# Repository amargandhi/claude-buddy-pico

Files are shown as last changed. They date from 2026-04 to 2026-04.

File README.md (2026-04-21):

# Claude Buddy Pico

A fun, playful Claude Code mascot brought to life with a 3D-printed case by porting Felix Rieseberg's original Claude Desktop buddy from the M5 ESP32 hardware to a custom Raspberry Pi Pico build with a bigger 2.8" display. Claude Pico sits next to your Mac, approves tool calls for [Claude Desktop](https://claude.ai/download) over Bluetooth, and reacts to what Claude is doing with a face that feels alive. One button approves, another denies, and the built-in rechargeable battery lets you take it around the office or house to keep an eye on things while you get on with your day.

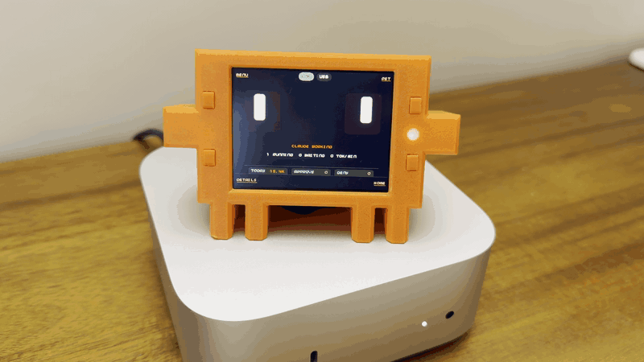
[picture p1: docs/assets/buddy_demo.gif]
Claude Buddy Pico V2 UI demo


Unofficial community port. Not produced or endorsed by Anthropic. Attribution in [NOTICE](NOTICE).

<p align="center">
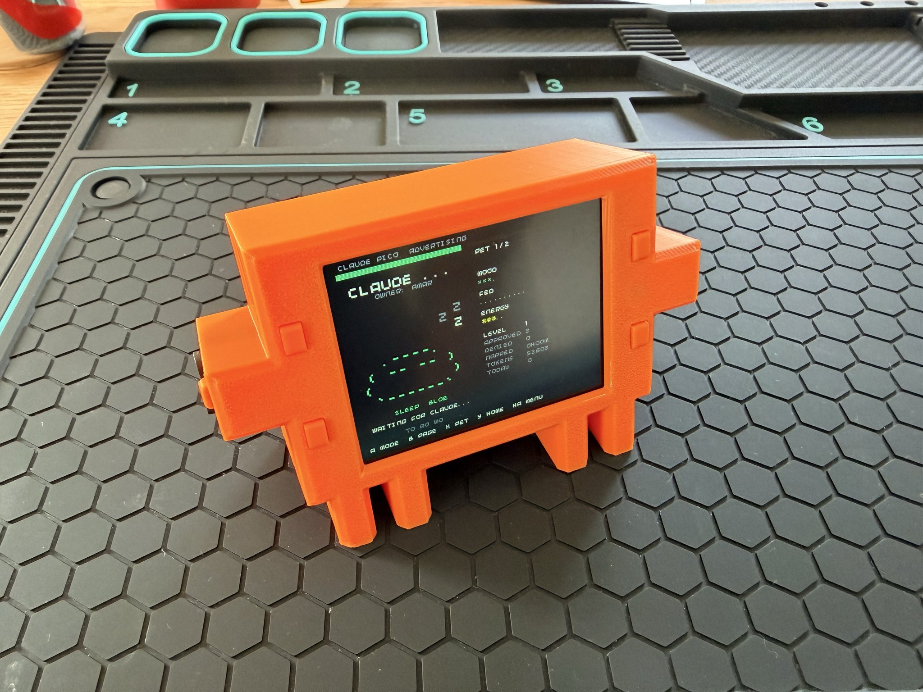
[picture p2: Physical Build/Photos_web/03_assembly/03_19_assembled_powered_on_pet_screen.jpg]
Claude Buddy Pico powered on in the printed case
  
  &nbsp;
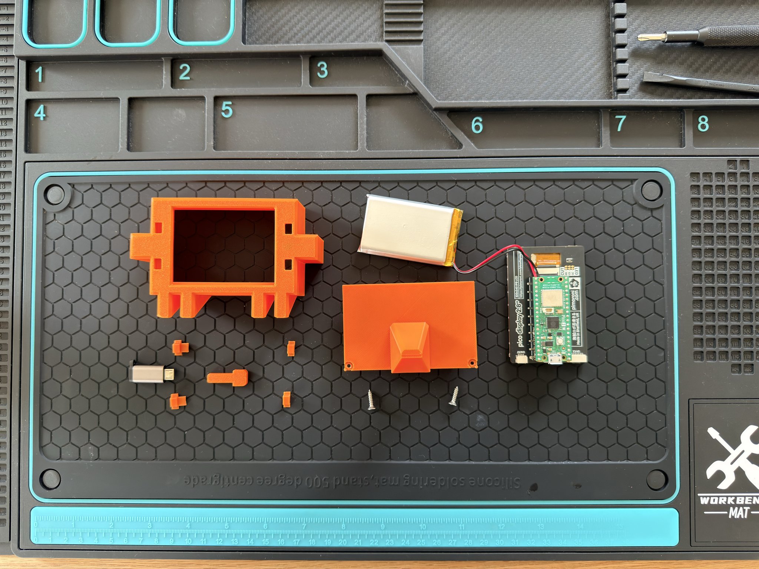
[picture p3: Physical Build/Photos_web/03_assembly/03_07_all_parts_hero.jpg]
All parts laid out: Pico 2 W, Pimoroni Display Pack 2.8, LiPo SHIM, 2000 mAh battery, 3D-printed Clawd case, M3 screws
  
</p>

Upstream: [anthropics/claude-desktop-buddy](https://github.com/anthropics/claude-desktop-buddy). Original author: [Felix Rieseberg](https://github.com/anthropics/claude-desktop-buddy/commits?author=felixrieseberg).

## What it is

- Raspberry Pi Pico 2 W + Pimoroni Display Pack 2.8 + optional LiPo SHIM and 2000 mAh battery.
- Pairs with Claude Desktop over Bluetooth Low Energy using the Hardware Buddy protocol.
- Runs tethered on USB, or untethered with the optional battery.
- 3D-printed case in the shape of Clawd. CAD in both `.step` (editable) and `.stl` (printable).
- MIT licensed; improvements and fixes are welcome.

## Pick a path

| If you want to… | Start here |
|---|---|
| Build one | [Physical Build/BUILD_GUIDE.md](Physical%20Build/BUILD_GUIDE.md) |
| Print the case | [Physical Build/CAD/](Physical%20Build/CAD) — GitHub renders `.stl` inline |
| Flash the firmware | [docs/software-setup.md](docs/software-setup.md) |
| Understand what changed from upstream | [docs/feature-matrix.md](docs/feature-matrix.md) |

## What changed from upstream

Three things matter; the rest is in [`docs/feature-matrix.md`](docs/feature-matrix.md):

- **Landscape 320×240 instead of the M5Stick portrait display.** The V2 UI is Pico-native, not a pixel copy of the original.
- **Four front buttons `A / B / X / Y` replace the M5Stick power-button semantics.** The LiPo SHIM button stays hardware-only.
- **No IMU.** Shake-to-dizzy became `Hold X`; face-down nap became `Hold Y`. Gestures are explicit.

The BLE Hardware Buddy protocol itself is unchanged — this device pairs with a stock Claude Desktop Hardware Buddy session.

## Controls

- `A`: next screen, approve prompt, advance selection
- `B`: next page, next transcript chunk, deny prompt
- `X`: next pet, raw prompt details during approvals
- `Y`: home / back
- `Hold A`: open the main menu
- `Hold X`: `dizzy` easter egg
- `Hold Y`: nap / wake
- `LiPo SHIM button`: hardware power only, never app input

Full screen-by-screen map in [`docs/user-guide.md`](docs/user-guide.md).

## Known limits

- **GIF character packs not implemented.** The transfer wire protocol works and `text` manifests render on-device; porting the upstream GIF renderer to the Pico is future work.
- **Battery percent is estimated from VSYS voltage.** No current-sense path on this build, so it's a voltage-curve approximation, not coulomb counting.
- **Case is v1.** Obvious things to improve: a proper integrated battery retainer instead of glued clips, a deeper USB cutout, tighter button-stem tolerance. The `.step` files are in the repo. Fork the case and open a PR — the v2 list is in the build guide.
- **Hardware Buddy feature gating.** If `Developer → Open Hardware Buddy…` is missing, you're on a Claude Desktop build that doesn't expose the feature yet — host-side, not firmware.

## Firmware — two paths

There are two ways to build the main firmware from the same `claude_buddy_pico` target. Both speak the same BLE protocol and pair with Claude Desktop the same way. They differ only in the on-device UI.

- **Main path — V2 with buddy animations (default).** Face expressions, animated pet, dock clock, approval screens, permissions log. Built with `BUDDY_UI_V2=1`, which is on by default.
- **Basic path — V1 monolith (fallback).** The original single-file UI from early bringup. Same BLE stack, simpler screens, no animations. Opt in with `-DBUDDY_UI_V2=OFF` at configure time. Useful if you're debugging the BLE layer and want the UI out of the way.

## Build

macOS toolchain:

```bash
scripts/bootstrap_macos.sh       # one-time
scripts/clone_deps.sh            # one-time
scripts/configure_firmware.sh    # V2 main path (default)
cmake --build build/pico
```

For the V1 basic path, configure with the flag off:

```bash
cmake -S . -B build/pico -DBUDDY_UI_V2=OFF
cmake --build build/pico
```

Either configure step produces `claude_buddy_pico.uf2` — the flag only changes which UI gets compiled in.

### Diagnostic builds

The same build also emits three smoke-test UF2s. Only flash these if something is wrong:

- `claude_buddy_pico_smoke.uf2` — hardware smoke test (display, buttons, LED)
- `claude_buddy_ble_smoke.uf2` — BLE/protocol smoke test
- `claude_buddy_pico_v2_smoke.uf2` — isolated V2 UI renderer, no BLE

If Homebrew's embedded toolchain install fails on your machine, `scripts/extract_local_toolchain.sh` extracts a workspace-local fallback. Full detail in [`docs/software-setup.md`](docs/software-setup.md).

## Flash

1. Disconnect the battery.
2. Hold `BOOTSEL`.
3. Plug USB into your Mac.
4. `cp build/pico/claude_buddy_pico.uf2 /Volumes/RP2350/`

`BOOTSEL` recovery with the battery attached is flaky on the LiPo SHIM. The battery-connected recovery path and the full story are in [`docs/hardware-build.md`](docs/hardware-build.md).

## Pair with Claude Desktop

1. Enable Developer Mode in Claude Desktop.
2. `Developer → Open Hardware Buddy…`
3. `Connect` → select `Claude Pico` → complete the passkey flow.

## Repo layout

- `src/` — active firmware targets and character renderer
- `src/ui_v2/` — V2 UI engine, screens, palette, face system, transitions
- `src/_legacy/` — archived bringup scaffold, not part of the current build
- `docs/` — protocol notes, feature matrix, limitations, and user guide
- `Physical Build/` — CAD, printable case, and the hardware build guide
- `scripts/` — bootstrap, dependency, and configure helpers
- `third_party/` — vendor SDK clones
- `toolchains/` — optional workspace-local embedded toolchain

## What to do next

- **Build the minimum version first** — Pico 2 W + Display Pack + USB cable. That proves the firmware works on your hardware before you commit to the SHIM solder.
- **Open the `.step` files** in Fusion / FreeCAD / Onshape. Fork the case and open a PR — the v2 list is in the build guide.

## Credits

The Hardware Buddy BLE protocol and the original M5Stick firmware are the work of Anthropic and are published at [anthropics/claude-desktop-buddy](https://github.com/anthropics/claude-desktop-buddy). Felix Rieseberg's original implementation is the foundation for this port. See [NOTICE](NOTICE) for attribution details.

## License

MIT. See [LICENSE](LICENSE).

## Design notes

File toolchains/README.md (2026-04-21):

# Local Toolchains

This directory is for workspace-local toolchains that do not need a system-wide install.

Use `scripts/extract_local_toolchain.sh` to unpack the cached Arm GNU embedded package here when the Homebrew cask install is not practical.

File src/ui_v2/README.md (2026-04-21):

# V2 UI module

The V2 UI engine for Claude Buddy Pico. Renders the face, screens, transitions, and approval flow against the 320×240 Display Pack. Selected at build time with `BUDDY_UI_V2=1` (on by default in `CMakeLists.txt`).

## Layout

```
src/ui_v2/
├── README.md               — this file
├── palette.h               — RGB332-safe colour palette
├── geometry.h              — layout constants and case-derived eye positions
├── gfx.h / gfx.cpp         — text / chip / rounded-rect helpers over PicoGraphics
├── eye.h / eye.cpp         — Eye parameter struct and renderer
├── expression.h / .cpp     — 18 expression parameter sets
├── face.h / face.cpp       — face engine: tween, blink cadence, saccades
├── transitions.h / .cpp    — merge_wipe, chip_pulse, wipe_down, fade
├── risk_tier.h / .cpp      — tool-name → SAFE/NEUTRAL/CAUTION/DANGER classifier
├── permissions_log.h / .cpp — 64-entry ring buffer of approval decisions
├── ui_state.h              — read-only state snapshot the screens consume
├── ui_core.h / ui_core.cpp — dispatcher: picks screen, runs face, commits frame
└── screens/
    ├── screen.h            — base Screen interface
    ├── boot.*              — boot sequence
    ├── sync.*              — pairing screen with large passkey
    ├── home.*              — face-dominant home
    ├── approval.*          — tool-aware approval overlay
    ├── stats.*             — paginated stats
    ├── usage.*             — tokens-today / projected EOD
    ├── permissions.*       — decision history
    ├── info.*              — 7-page reference
    ├── pet.*               — pet in main cycle
    ├── settings.*          — settings list
    ├── reset.*             — reset submenu
    ├── system_menu.*       — Hold-A system menu
    ├── dock_clock.*        — dock clock
    └── demo.*              — demo mode scene runner
```

## Integration surface

`ui_core.h` exposes three entry points:

```cpp
ui_v2::core::init(pimoroni::PicoGraphics* gfx, uint32_t initial_seed, uint32_t now_ms);
ui_v2::core::tick_40ms(const ui_v2::BuddyInputs& in, ui_v2::BuddyOutputs& out, uint32_t now_ms);
ui_v2::core::on_button_event(ui_v2::Button, ui_v2::ButtonEdge, uint32_t now_ms);
```

`src/claude_buddy_pico.cpp` remains authoritative for BLE, pairing, protocol parsing, persistence, and the `BuddyState` struct. It fills a read-only `BuddyInputs` snapshot once per tick and acts on the `BuddyOutputs` V2 writes back (approve/deny, persist-dirty, LED, backlight).

## Build targets

- `claude_buddy_pico` — main firmware; compiled with `BUDDY_UI_V2=1` by default. Build with `-DBUDDY_UI_V2=OFF` for the V1 fallback UI.
- `claude_buddy_pico_v2_smoke` — V2 screens against a synthetic input bus. Flashable without BLE or protocol state; useful for iterating on layouts on real hardware.

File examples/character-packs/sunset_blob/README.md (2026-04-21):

# Sunset Blob

Known-good sample text character pack for the Pico Buddy port.

Use this folder as the first folder-push test from Claude Desktop Hardware Buddy:

1. Open `Developer -> Open Hardware Buddy...`
2. Make sure `Claude Pico` is connected.
3. Drag this folder into the `Drop a data folder here` area.
4. Click `Send to Device`.

Expected result on the Pico:

- install progress overlay appears
- banner changes to `Installing character pack`
- the pack becomes selectable in settings and via `X`

If you want to remove it again, open:

- `Hold A` -> `settings` -> `reset` -> `delete char`

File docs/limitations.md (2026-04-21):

# Limitations And Future Work

## Current Limitations

- The pushed character-pack renderer currently supports `text` manifests on-device. Upstream-style GIF pack rendering still needs a Pico-native decode and asset pipeline.
- The battery percentage is estimated from `VSYS` voltage. There is no direct current-sense path on this build, so the number is a voltage-curve approximation rather than true coulomb counting.
- Reflashing is documented through `BOOTSEL` and drag-drop UF2. A `picotool`-driven reboot/load path would make the in-firmware reflash flow smoother but has not been wired up yet.
- The case and build guide are included, but the enclosure is still v1. The obvious next fixes are a better integrated battery retainer, a deeper USB cutout, and button stems that need less break-in.

## Good Next Steps

- Add a Pico-friendly GIF asset pipeline for pushed character packs.
- Wire up a `picotool`-based reboot-to-BOOTSEL path so the `BOOTSEL` button becomes a fallback rather than the primary flash workflow.
- Tighten the v2 case revision: battery retainer, USB cutout, and button-stem tolerance.
- Add a simpler first-time-builder path that focuses on the minimum USB-powered build before the portable stack.

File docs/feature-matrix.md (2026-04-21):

# Feature Matrix

## Original Buddy To Pico Mapping

| Upstream Buddy Feature | Pico Hardware Equivalent | Status | Notes |
| --- | --- | --- | --- |
| M5Stick portrait pet screen | 320x240 landscape pet column + side rail | Adapted | Pico uses a left pet column and right content panel |
| `A` next / approve | `A` next / approve | Kept | Same role as upstream |
| `B` page / deny | `B` page / deny | Kept | Transcript paging is chunked and labeled on-screen |
| power button menu semantics | `Y` home/back and `Hold A` menu | Adapted | SHIM button remains hardware-only |
| shake to dizzy | `Hold X` dizzy | Adapted | No IMU on Pico build |
| face-down nap | `Hold Y` nap / wake | Adapted | Explicit control instead of IMU gesture |
| speaker / beep cues | none | Removed | No speaker on this hardware |
| RGB LED | Display Pack RGB LED | Kept | Used for pairing, busy, prompt, low battery |
| idle charging clock | fixed landscape dock clock | Adapted | Only when USB + time sync + idle |
| ASCII species built into firmware | ASCII species built into firmware | Kept | 18 built-in pets remain available |
| single installed pushed character | single installed pushed character | Kept | Stored in flash on Pico |
| GIF character rendering | text-manifest character rendering | Partial | Transfer wire protocol is present; Pico GIF renderer is future work |
| `status` reply | `status` reply | Kept | Validated against Claude Desktop during bring-up |
| `name`, `owner`, `unpair`, `species` | same | Kept | Persisted in Pico flash |
| `char_begin/file/chunk/file_end/char_end` | same | Kept | Used for installing one pushed text pack |

## Settings On Pico

Persisted settings buckets:

- brightness
- LED enabled
- transcript enabled
- demo mode
- dock clock enabled
- selected pet / character
- device name
- owner

Persisted stats buckets:

- approvals
- denials
- response velocity ring
- nap time
- level
- cumulative tokens

## Known Differences Worth Calling Out Publicly

- The Pico build is intentionally Pico-first, not a pixel clone of the M5Stick UI.
- The screen is used for clearer hierarchy instead of strict upstream layout parity.
- The LiPo SHIM button is never treated as a normal app button.
- The current pushed-pack renderer supports `text` manifests. Upstream-style GIF packs still need a Pico-native renderer pass.

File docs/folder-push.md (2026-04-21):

# Folder Push

The Pico port supports one installed pushed character pack at a time.

Current renderer scope:

- supported on-device format: `text` manifest packs
- supported wire protocol: `char_begin`, `file`, `chunk`, `file_end`, `char_end`
- not supported yet: upstream GIF-pack rendering

## First Test

Use the sample pack in [../examples/character-packs/sunset_blob](../examples/character-packs/sunset_blob).

In Claude Desktop:

1. Open `Developer -> Open Hardware Buddy...`
2. Connect to `Claude Pico`
3. Drag the `sunset_blob` folder into the folder drop area
4. Click `Send to Device`

Expected behavior:

- the Pico shows an install progress panel
- the left banner changes to `Installing character pack`
- the LED switches to the pairing/install color
- after `char_end`, the pack becomes the active custom species

## Manifest Shape

The current Pico parser expects a `manifest.json` file with:

- `mode`: optional, but if present it must be `text`
- `name`: pack display name
- `colors`: optional hex colors using `#RRGGBB`
- `states`: object keyed by Buddy state name

State names:

- `sleep`
- `idle`
- `busy`
- `attention`
- `celebrate`
- `dizzy`
- `heart`

Each state can include:

- `delay`: frame delay in milliseconds
- `frames`: array of up to 8 short text frames

Current practical limits:

- frame strings should stay under about 24 characters
- the manifest must fit inside the device transfer buffer
- only one pushed custom pack is stored at a time

## Remove Or Replace A Pack

To remove the current custom pack on-device:

1. `Hold A`
2. `settings`
3. `reset`
4. `delete char`

Sending a new pack replaces the previous custom pack.

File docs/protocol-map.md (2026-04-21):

# Protocol And UI Map

## Final Button Map

- `A`: next main screen, approve prompt, advance selection in overlays
- `B`: next page or transcript chunk, deny prompt, choose in overlays
- `X`: cycle pet normally, toggle raw prompt details during approvals
- `Y`: home / back
- `Hold A`: open or close the main menu
- `Hold X`: one-shot `dizzy`
- `Hold Y`: nap / wake
- `LiPo SHIM button`: hardware-only power

## Screen Model

The Pico port keeps the upstream Buddy model, but adapts it to the larger landscape display:

- left column: pet + state banner
- right column: `Home`, `Pet`, or `Info`
- centered overlays: prompt, menu, settings, reset

## Buddy State Mapping

- `sleep`: disconnected, stale heartbeat, manual nap, or screen-off state
- `idle`: linked and calm
- `busy`: `running > 0`
- `attention`: `waiting > 0` or prompt pending
- `celebrate`: completion / level-up one-shot
- `dizzy`: manual easter egg via `Hold X`
- `heart`: quick approval one-shot

## LED Map

- `off`: asleep / not linked
- `green`: linked and calm
- `blue`: Claude is running work
- `amber`: approval pending
- `magenta`: pairing or character install
- `red`: battery low

The current firmware intentionally drives the LED below full power so it is visible without overwhelming the display in a dim room.

## Protocol Commands Implemented

Required Buddy commands:

- `status`
- `name`
- `owner`
- `species`
- `unpair`

Permission replies:

- `once`
- `deny`

Character transfer flow:

- `char_begin`
- `file`
- `chunk`
- `file_end`
- `char_end`

## Heartbeat Behavior

Heartbeat snapshots remain the main source of truth for:

- session counts
- message text
- transcript entries
- prompt presence
- tokens / tokens today
- recently completed state

`evt:"turn"` is treated as optional decoration only, not critical UI state.

## Character Packs

The Pico port supports:

- built-in ASCII pets compiled into firmware
- one installed pushed character pack stored in flash

Current renderer scope:

- installed `text` character manifests are supported on-device
- the wire protocol for pushed packs is implemented
- GIF-pack rendering from the upstream ESP32 project is not yet implemented here

## Dock Clock

The dock clock is a Pico-specific adaptation of the upstream idle clock idea:

- fixed landscape only
- only appears on USB power
- only appears when a bridge time sync has been received
- only appears when the Buddy is idle and no overlay is active

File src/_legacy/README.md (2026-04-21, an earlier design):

These files are the earlier modular bring-up scaffold.

They are intentionally not part of any current CMake target.

They remain here as historical reference while the shipped firmware lives in `src/claude_buddy_pico.cpp`.

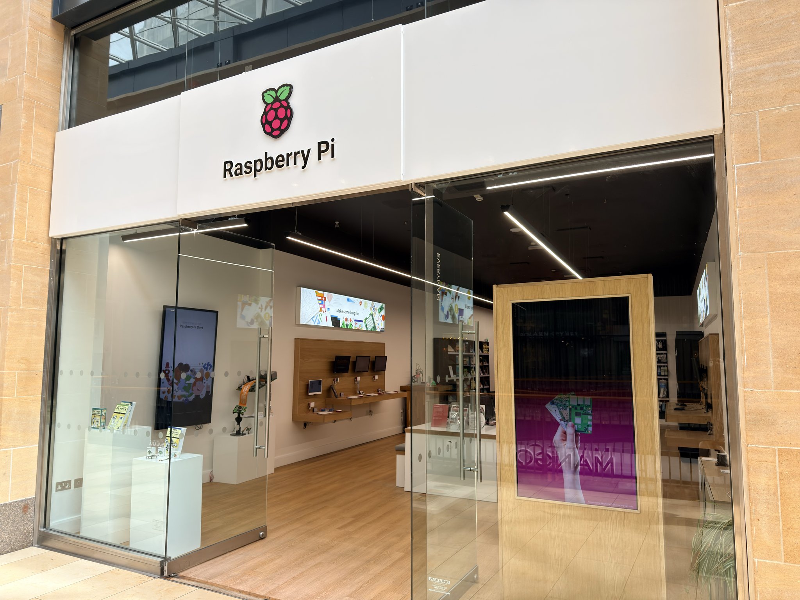
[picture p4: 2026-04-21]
Physical Build/Photos_web/01_hardware/01_01_origin_raspberry_pi_store.jpg

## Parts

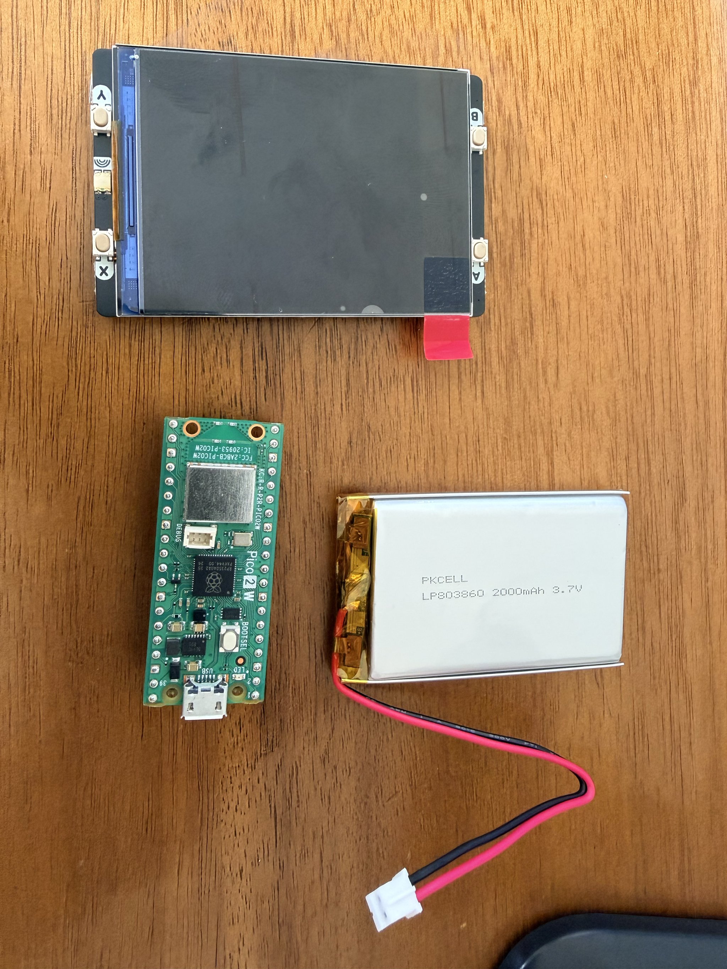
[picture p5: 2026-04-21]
Physical Build/Photos_web/01_hardware/01_07_parts_layout_b.jpg

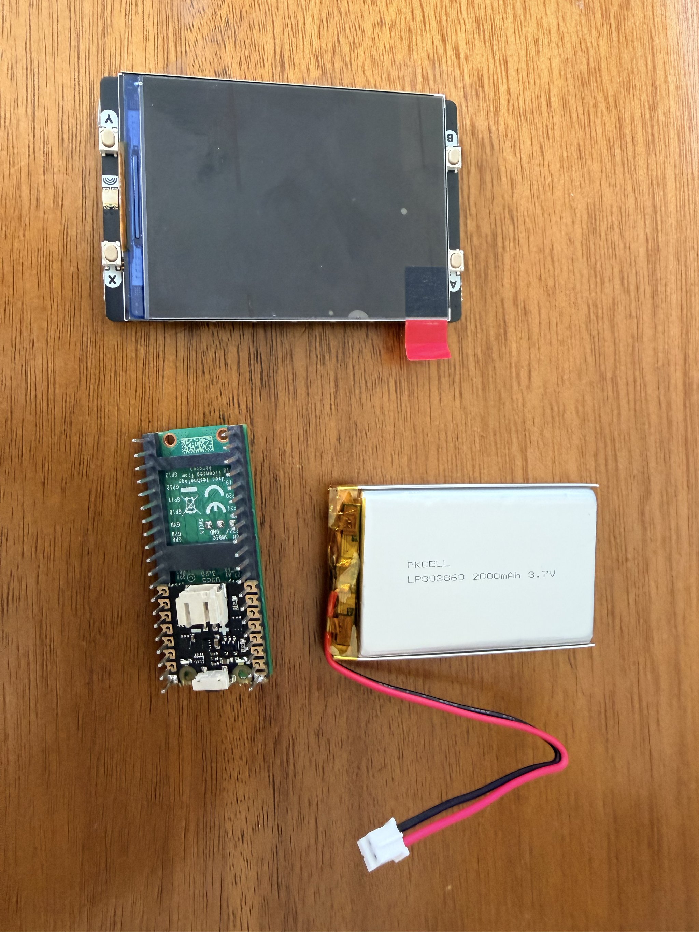
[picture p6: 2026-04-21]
Physical Build/Photos_web/01_hardware/01_09_parts_layout_pico_underside.jpg

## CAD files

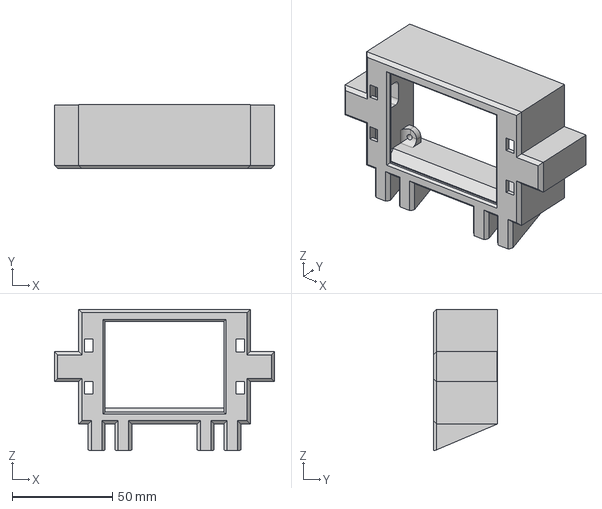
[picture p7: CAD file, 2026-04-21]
Physical Build/CAD/Claude_Pico_Case_Main_Body.step
109.5 x 32.0 x 70.3 mm

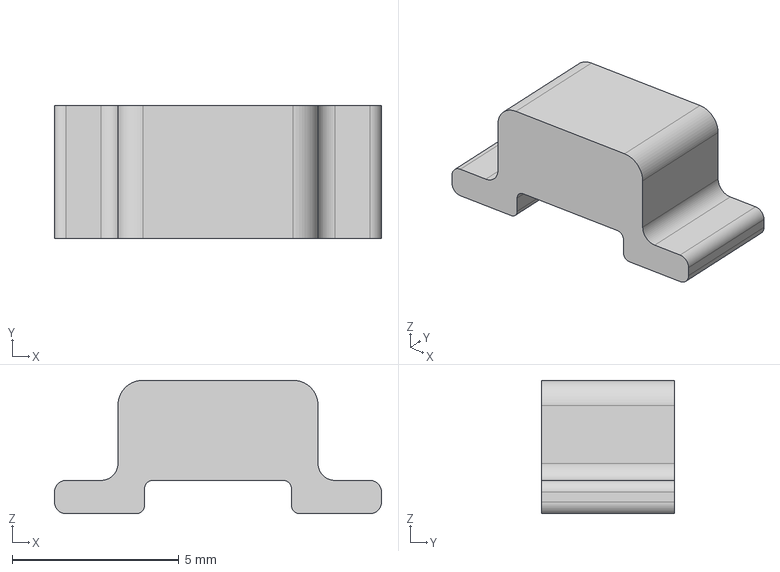
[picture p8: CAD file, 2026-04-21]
Physical Build/CAD/Claude_Pico_Right_Side_Button.step
9.80 x 4.00 x 4.00 mm

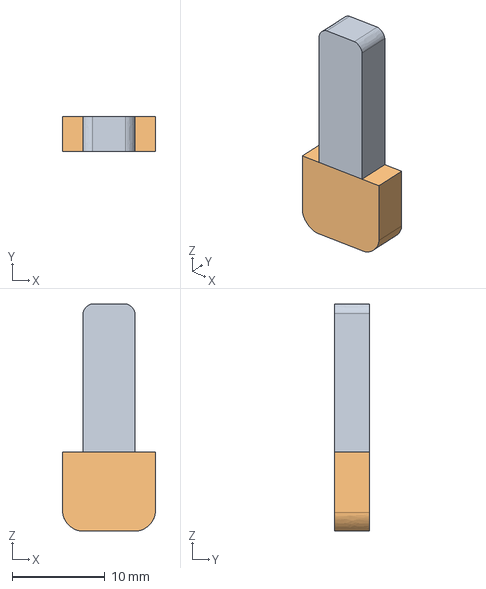
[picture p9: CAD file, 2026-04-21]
Physical Build/CAD/Claude_Pico_Power_Button.step
10.0 x 3.80 x 24.5 mm

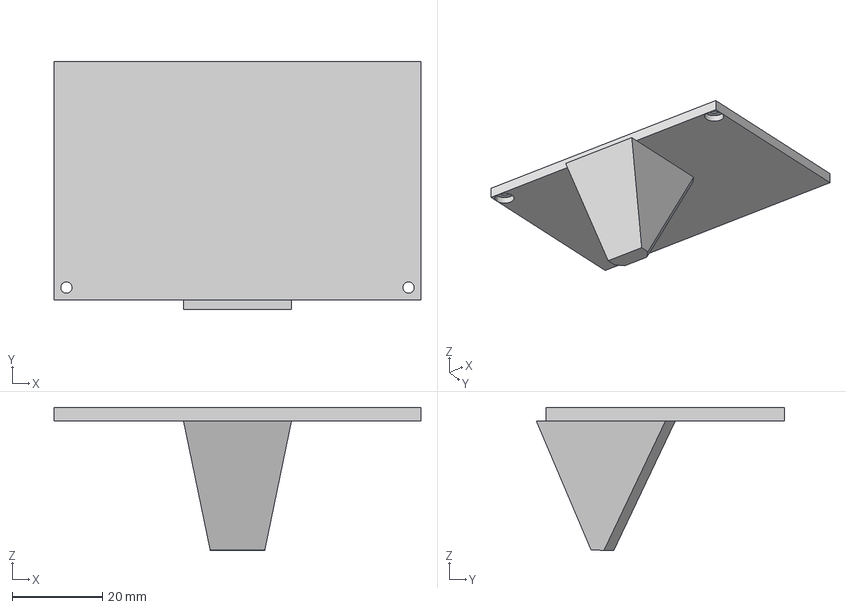
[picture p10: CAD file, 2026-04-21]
Physical Build/CAD/Claude_Pico_Case_Rear_With_Tail.step
81.5 x 55.2 x 31.8 mm

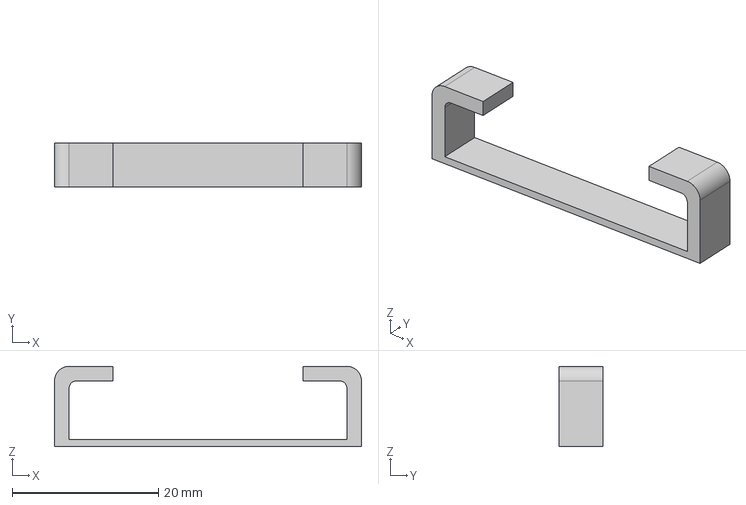
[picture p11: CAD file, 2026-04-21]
Physical Build/CAD/Claude_Pico_Battery_Clip.step
42.0 x 6.00 x 11.0 mm

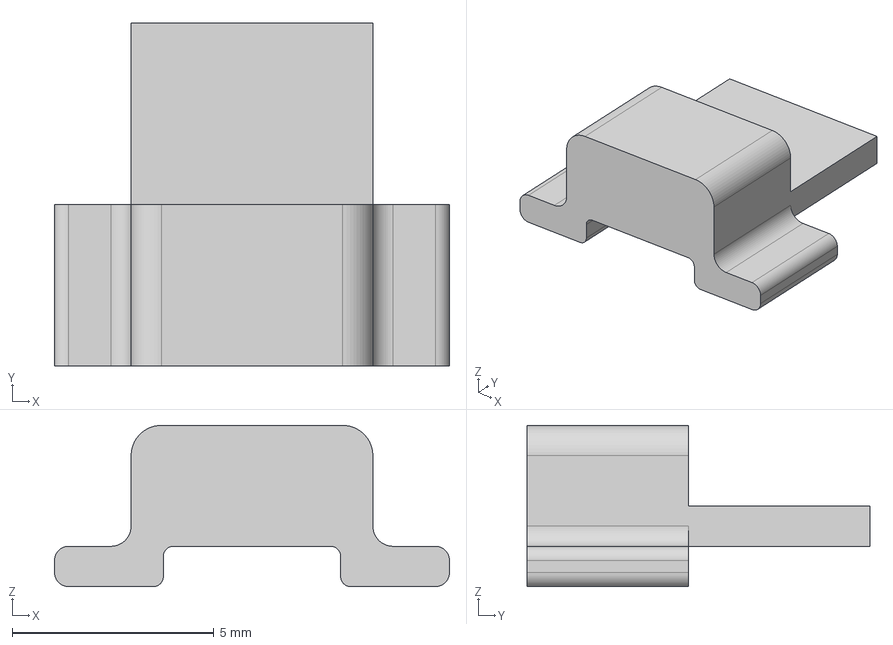
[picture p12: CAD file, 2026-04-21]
Physical Build/CAD/Claude_Pico_Left_Side_Button.step
9.80 x 8.50 x 4.00 mm

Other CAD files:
Physical Build/CAD/Claude_Pico_Battery_Clip.stl
Physical Build/CAD/Claude_Pico_Case_Main_Body.stl
Physical Build/CAD/Claude_Pico_Case_Rear_With_Tail.stl
Physical Build/CAD/Claude_Pico_Left_Side_Button.stl
Physical Build/CAD/Claude_Pico_Power_Button.stl
Physical Build/CAD/Claude_Pico_Right_Side_Button.stl

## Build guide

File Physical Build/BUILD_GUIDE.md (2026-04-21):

# Claude Pico Desktop Buddy — Build Guide

A small BLE buddy for [Claude Desktop](https://claude.ai/download). Raspberry Pi Pico 2 W, Pimoroni Display Pack 2.8, optional battery, 3D-printed case in the shape of the Claude Code mascot. Pairs over Bluetooth Low Energy using Anthropic's Hardware Buddy protocol.

Assembled Claude Pico Buddy

The CAD is in `.step` so it can be edited and remixed.

- Repo: [../README.md](../README.md)
- Firmware notes: [../docs/hardware-build.md](../docs/hardware-build.md), [../docs/software-setup.md](../docs/software-setup.md)
- Printable files (`.stl` and `.step`): [CAD/](CAD/)
- Photos used in this guide: [Photos_web/](Photos_web/)

---

## Why this exists

Felix Rieseberg's Hardware Buddy looked like a good side project when I'd run out of Claude usage and was waiting for the next 5-hour block to start again. Cambridge helps here: Raspberry Pi has a shop I can wander into at lunch, so getting the parts was easy. The catch was that Felix's original build was for different hardware, which meant I then had to port the whole thing to the Pico 2 W.

This ended up being a relatively low-cost build. The Display Pack 2.8 felt like the best screen for the size and money. E-ink was tempting. A bigger panel was tempting too. This one felt like the right compromise for something that can sit on top of a Mac mini, or be picked up and taken to the kitchen while the agents are coding and you're doing something else around the house.

The case is designed around the portable stack, but the same firmware also runs as a simpler USB-powered build with just the Pico 2 W and Display Pack.

---

## Two builds, same firmware

The main thing you need is a **Pico 2 W and a Display Pack**. That's the minimum build. Plug it into USB, flash the firmware, pair with Claude Desktop, and leave it on your desk. If you only want a tethered buddy, stop there.

The portable build adds the **LiPo SHIM and a battery** so you can carry it around. The case is designed around the portable build — the rear panel has a battery cavity and the screw posts assume the SHIM stack height — but a tethered minimum build will run the same firmware identically.

Everything below describes the portable build. If you're doing the minimum build, skip the SHIM solder step and the battery steps; the rest is the same.

---

## 1. What you need

### Electronics

| Qty | Part | Source | Notes |
|----:|---|---|---|
| 1 | Raspberry Pi Pico 2 W with headers | [Pimoroni / Pi Hut / official](https://shop.pimoroni.com/) | Soldered headers, not bare pads. |
| 1 | Pimoroni Pico Display Pack 2.8 | `PIM715` | 320×240 IPS, four buttons, RGB LED. |
| 1 | Pimoroni LiPo SHIM for Pico | `PIM557` | Portable build only. |
| 1 | LiPo battery, 2000 mAh, 3.7 V, JST-PH | PKCELL LP803860 or similar | Portable build only. Any 3.7 V LiPo with a JST-PH plug in roughly that footprint will fit the cavity. |
| 1 | USB-micro cable, **or** USB-C cable + USB-micro-to-USB-C adapter | generic | The case really wants a thin micro plug or a compact adapter — see note below. |

**About the USB connector.** The Pico is USB-micro. The case works with a thin USB-micro cable. If your cable has a chunky overmoulded plug, use a small USB-micro-to-USB-C adapter instead. The left-side cutout is larger specifically so that adapter can fit. I don't know the exact adapter brand I used, but Amazon is full of ones in roughly the same size and most of them should fit.

### 3D-printed parts (see [CAD/](CAD/))

Six parts. Both `.stl` (slice-ready) and `.step` (parametric — open in Fusion / FreeCAD / Onshape and change anything you like).

| File stem | Qty | What it is |
|---|----:|---|
| `Claude_Pico_Case_Main_Body` | 1 | Front shell. Screen window, side button slots, power-button pocket. |
| `Claude_Pico_Case_Rear_With_Tail` | 1 | Rear panel with the Claude Code mascot tail. |
| `Claude_Pico_Battery_Clip` | 1 | Holds the battery against the inside of the rear panel. Glued. |
| `Claude_Pico_Power_Button` | 1 | Actuator for the LiPo SHIM's power button. |
| `Claude_Pico_Left_Side_Button` | 1 | Actuator for the display's `A` / `B` column. |
| `Claude_Pico_Right_Side_Button` | 1 | Actuator for the display's `X` / `Y` column. |

**Why three separate side buttons.** The display PCB's flex connector eats about 5 mm on one side, so the screen sits off-centre relative to the display PCB. An uncentered display would have driven me mad, so I centered the display in the case and let the button geometry absorb the offset instead. The buttons have enough tolerance, but they usually smooth out after a few repeated clicks.

### Fasteners and consumables

| Qty | Part | Notes |
|----:|---|---|
| 2 | M3 × 12 mm self-tapping screw | Rear panel into main body. |
| — | Super glue | Bonds the battery clip to the rear panel. |

### Tools

Soldering iron, thin solder, flux. Small Phillips screwdriver. Multimeter is useful for the pre-power continuity check. Tweezers. A Mac with Homebrew for the toolchain (Linux works too — the scripts are portable).

### Software

[Claude Desktop](https://claude.ai/download) with Developer Mode enabled.

All parts laid out

---

## 2. Print the case

Six parts, all small. I printed mine in **ABS on a Bambu P1S with default settings** because that was the only orange filament I had around. PLA should also be fine; the case has no real thermal duty.

Orientation:

- **Main body** — screen opening facing up. Supports under the side-button overhangs only.
- **Rear panel with tail** — flat back on the bed, tail facing up. No supports.
- **Battery clip** — flat side down. No supports.
- **Three buttons** — cap up, stem pointing into the build plate. No supports. Batch all three on the same plate.

The `.step` files are there so you can edit the actual CAD and improve it. This was a side project over a weekend, not a finished enclosure program. The obvious places to start are the button stems, the USB cutout, and a better battery retainer.

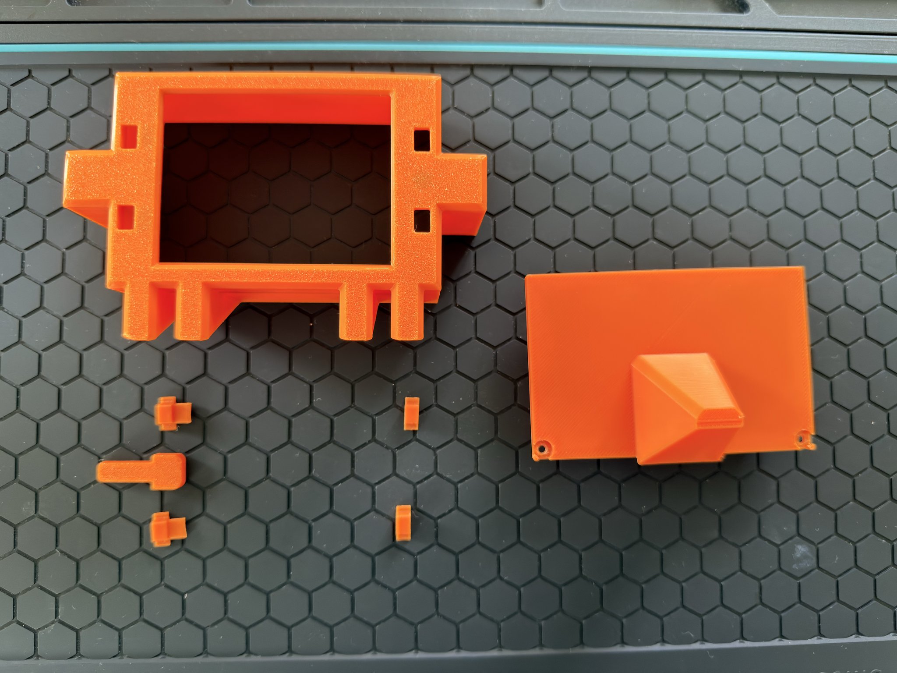
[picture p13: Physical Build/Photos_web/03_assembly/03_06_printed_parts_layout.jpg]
3D-printed parts


---

## 3. Build the Pico stack

Three boards: Pico 2 W → LiPo SHIM → Display Pack.

### 3.1 Dry-fit before soldering

With nothing soldered and no battery attached, push the Pico onto the Display Pack's female headers. It should seat with no force on the glass. If it doesn't sit flat, find what's obstructing it before going further.

### 3.2 Solder the LiPo SHIM

Pull the Pico off the display. Place the LiPo SHIM on the back of the Pico (opposite the RF can). The SHIM's silkscreen aligns with a subset of the Pico header pins. The JST connector ends up pointing away from the USB port.

Solder one pin at a time from the Pico side. Inspect under magnification for bridges when done — `VBUS`, `VSYS`, `3V3_EN`, `3V3` are the ones that turn a working build into a dead one. A multimeter in continuity mode takes a minute and saves hours.

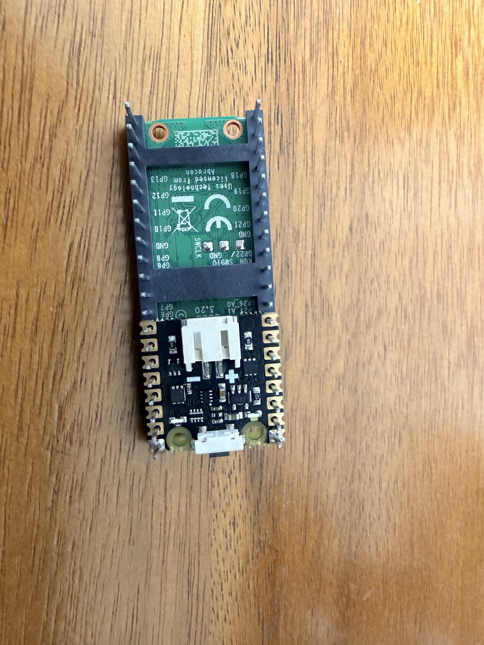
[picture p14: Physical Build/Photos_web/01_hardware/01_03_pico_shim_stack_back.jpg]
Pico + SHIM, back


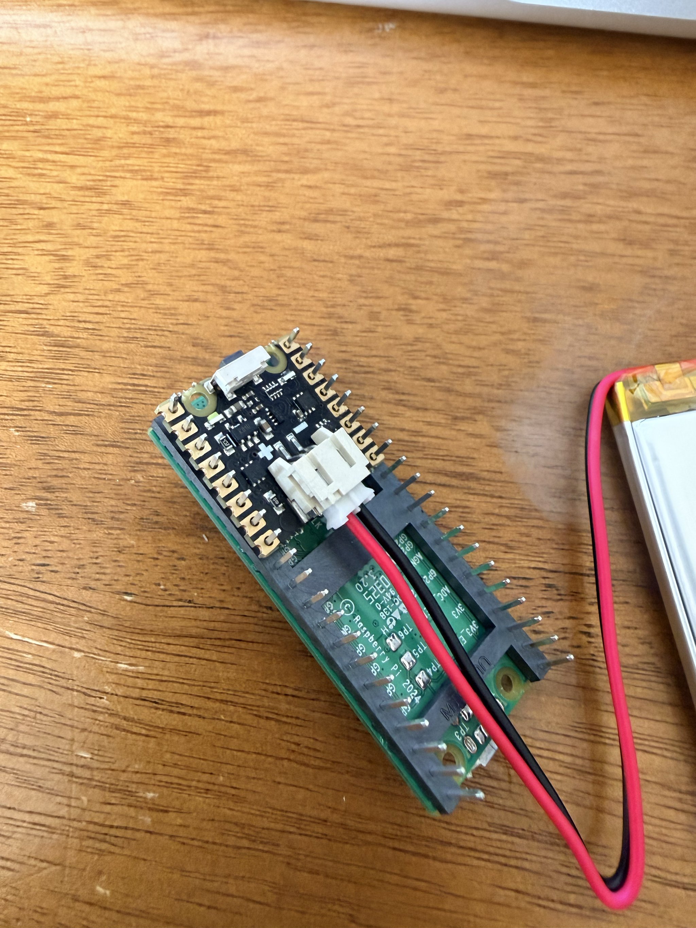
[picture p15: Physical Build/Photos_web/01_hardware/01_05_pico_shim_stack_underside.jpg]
Pico + SHIM, underside with battery JST


### 3.3 Refit the Pico into the display

Press the Pico-plus-SHIM stack back into the Display Pack. The display silkscreen reads upside-down when the USB port points up — that's the right orientation for this case.

---

## 4. Flash the firmware

Build it from the repo:

```bash
scripts/bootstrap_macos.sh      # one-time
scripts/clone_deps.sh           # one-time
scripts/configure_firmware.sh
cmake --build build/pico
```

This produces three UF2s. The full one is `build/pico/claude_buddy_pico.uf2` — that's the one to flash. The other two (`claude_buddy_pico_smoke.uf2` and `claude_buddy_ble_smoke.uf2`) are there for troubleshooting. Skip them unless something breaks.

Flash:

1. Disconnect the battery.
2. Hold the SHIM's power button (or `BOOTSEL` on a minimum build).
3. Plug USB into your Mac.
4. Wait for the `RP2350` volume to mount.
5. `cp build/pico/claude_buddy_pico.uf2 /Volumes/RP2350/`

Toolchain detail in [../docs/software-setup.md](../docs/software-setup.md).

### Pair with Claude Desktop

1. Open Claude Desktop, enable Developer Mode.
2. `Developer → Open Hardware Buddy…`
3. `Connect`, pick `Claude Pico`, complete the passkey flow.

When pairing succeeds the Pico shows the linked state and reacts to Claude Desktop activity.

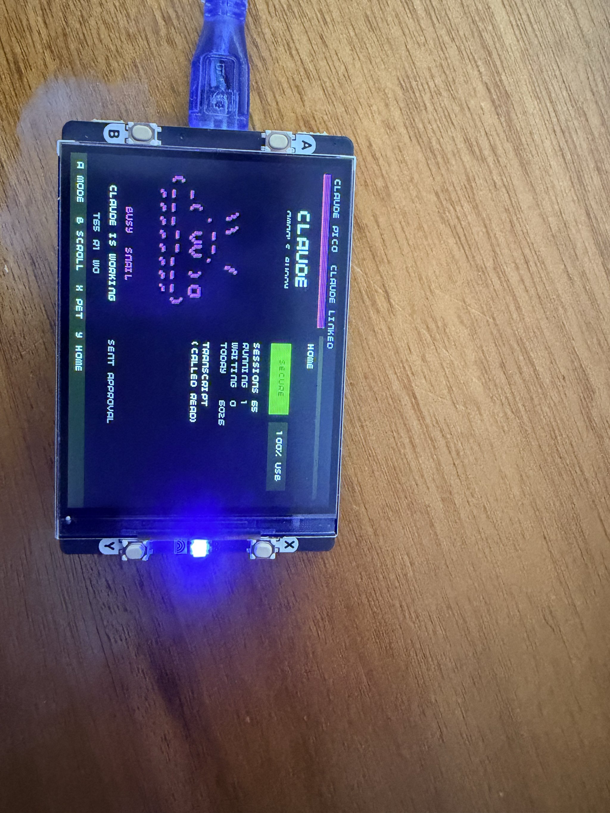
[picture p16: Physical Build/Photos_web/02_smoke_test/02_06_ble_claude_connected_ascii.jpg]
Claude connected, ASCII buddy on screen


Before you assemble the case, leave the firmware running off battery for 15 minutes and confirm nothing gets warm. Thermal problems are much harder to diagnose once the case is closed.

---

## 5. Assemble the case

Boot the firmware into the Pico/display board first. Then do the assembly in this order.

### 1. Place the four side buttons into the main body

From the inside, push each printed button through its slot until the cap protrudes about 1 mm. They're a friction fit. Two on the left for `A` / `B`, two on the right for `X` / `Y`.

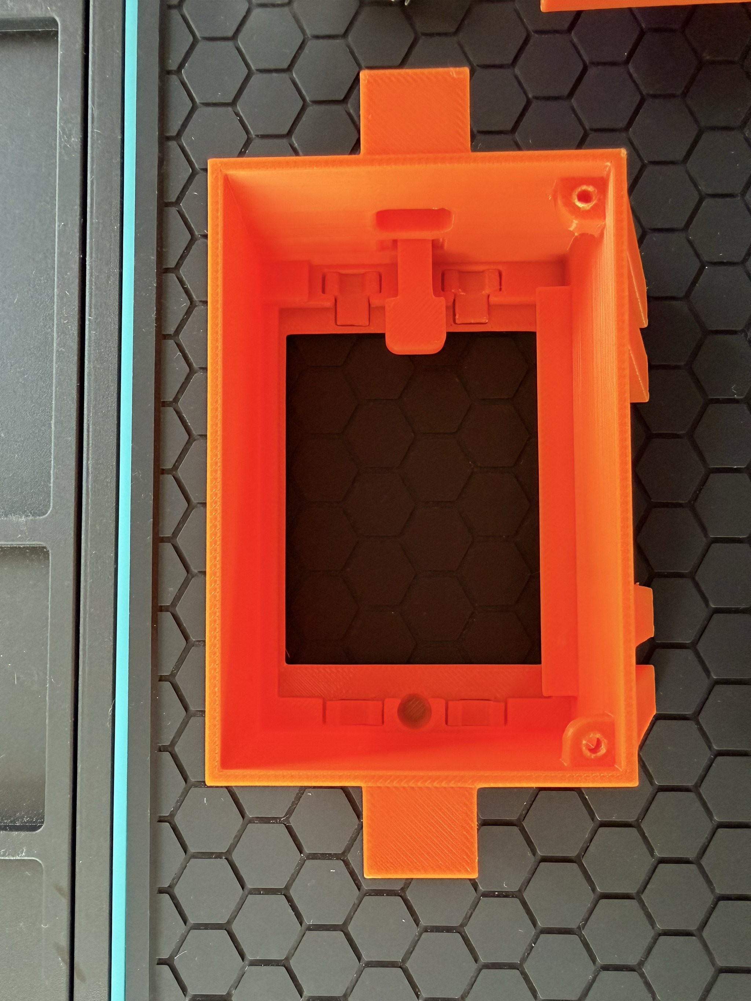
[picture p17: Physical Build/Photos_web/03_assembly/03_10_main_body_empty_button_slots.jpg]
Empty main body, button slots visible


### 2. Slide the power button into its slot, all the way

The power button is the printed actuator for the LiPo SHIM's side button. Slide it in fully so it bottoms out.

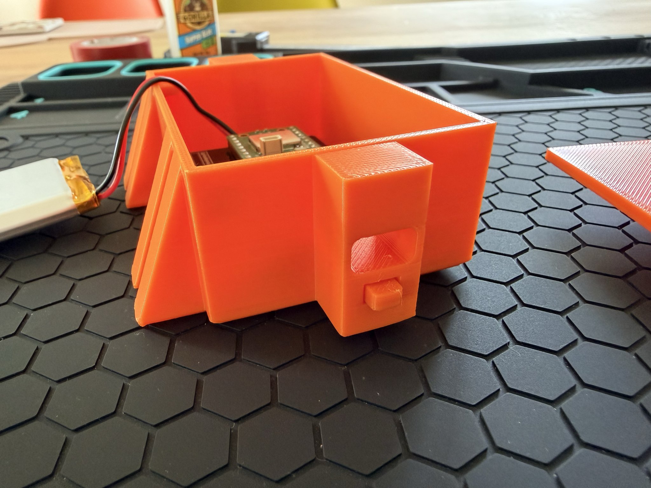
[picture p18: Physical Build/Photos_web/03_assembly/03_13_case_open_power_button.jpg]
Case open, power button in slot


### 3. Angle the assembled Pico/display board into the case

Tilt the stack in display-first, then press down. It should snap fit. The display glass should land flat against the screen window.

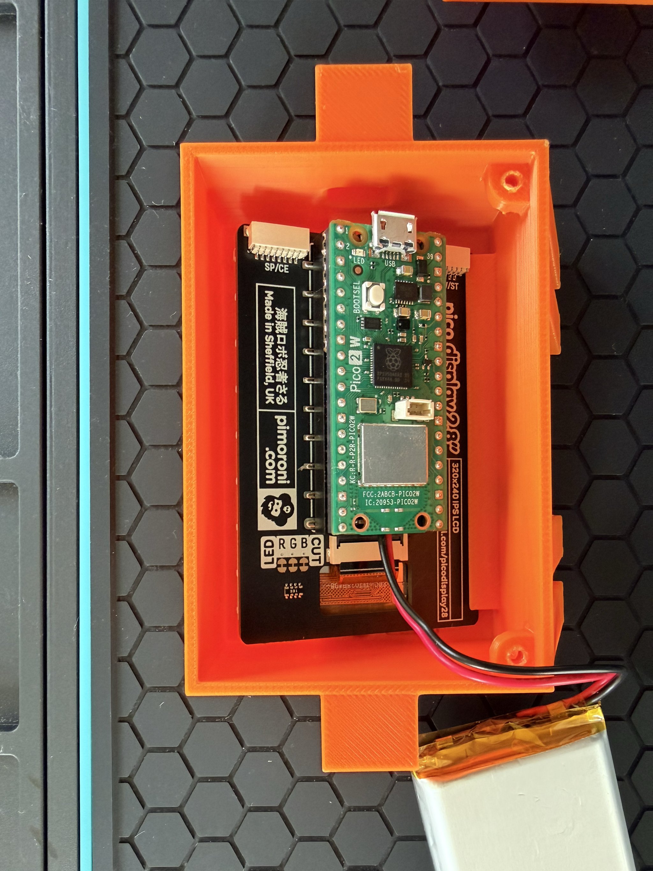
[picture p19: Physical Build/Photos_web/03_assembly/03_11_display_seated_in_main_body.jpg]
Display seated in main body


### 4. Push the USB connector through the left-hand cutout

Push the USB-C adapter (or the micro plug) through the cutout on the left. I usually seat the Pico/display stack nearly all the way down first, then adjust from there. If the connector doesn't line up cleanly, push the Pico in a little more or pull it back up a touch. The fit is loose enough that this is easy.

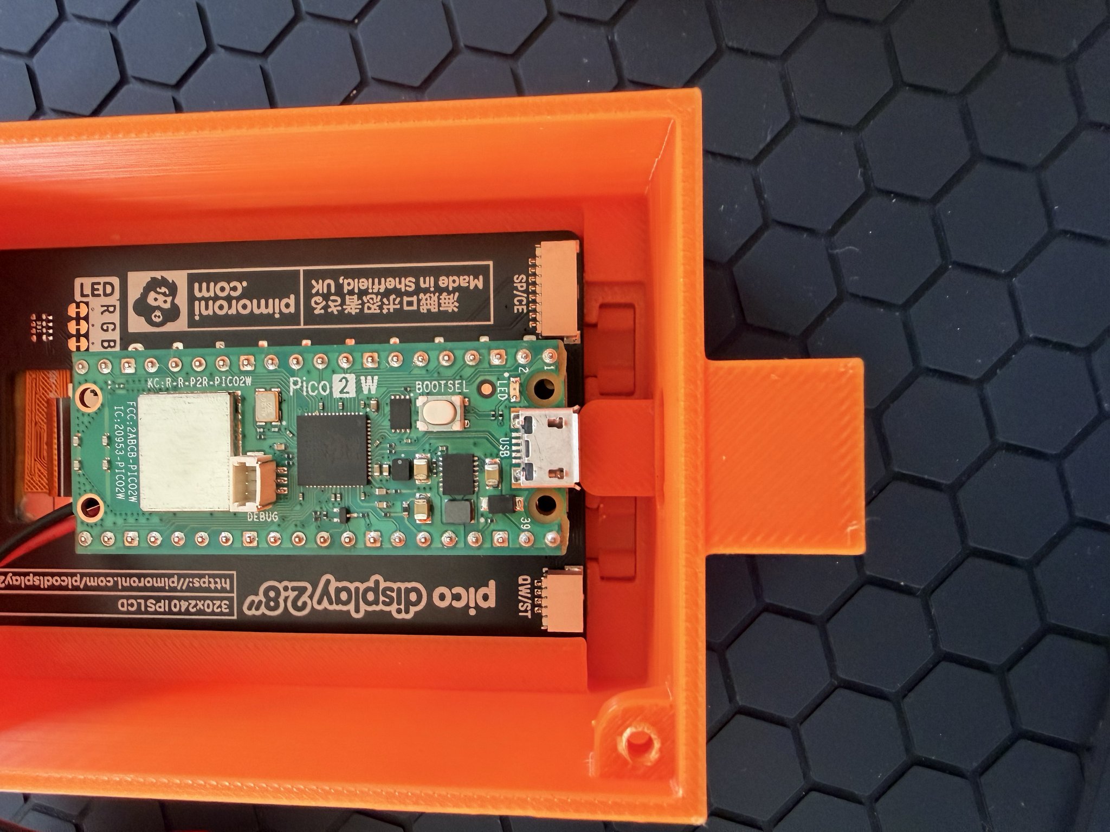
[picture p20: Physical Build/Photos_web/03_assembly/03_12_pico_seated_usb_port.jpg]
Pico seated, USB port visible


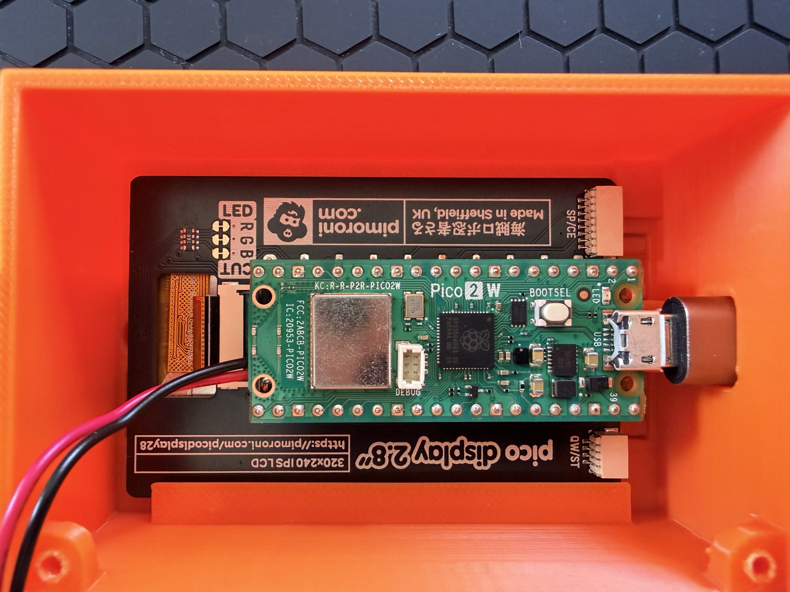
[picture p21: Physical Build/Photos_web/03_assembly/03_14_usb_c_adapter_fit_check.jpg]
USB-C adapter fit check


### 5. Slide the battery into the rear case

The battery clip is glued to the inside of the rear panel (see note below). Slide the battery into the clip. Route the JST lead toward the SHIM end so the wire doesn't sit across the RF can.

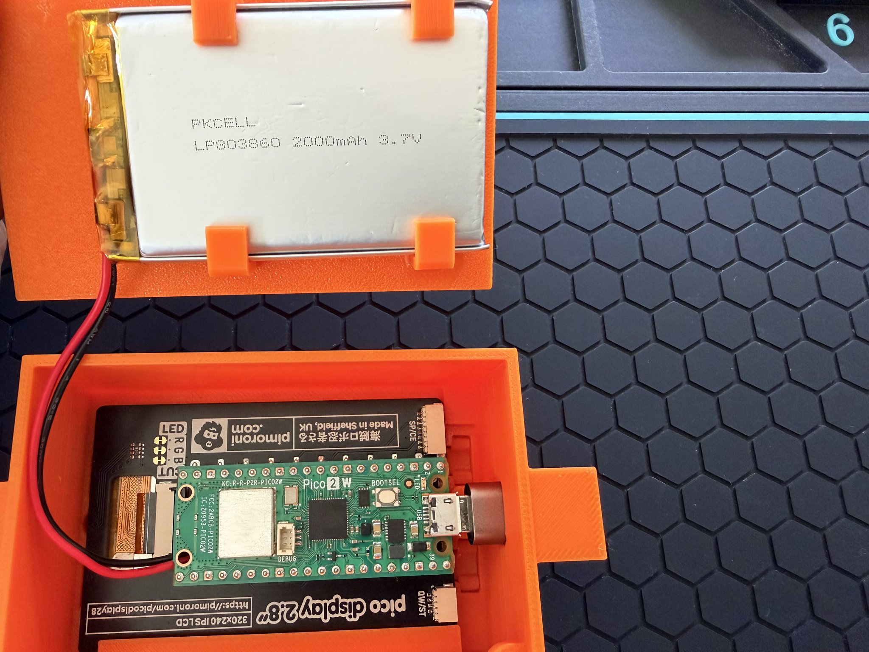
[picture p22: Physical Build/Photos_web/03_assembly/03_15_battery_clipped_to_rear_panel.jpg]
Battery clipped to rear panel


**About the battery clip.** I was getting tired, so I just glued the clips to the back of the rear case with super glue. It works. An integrated retainer would be better.

### 6. Two M3 × 12 screws

Bring the rear panel up to the main body, tail pointing down. The screws go through the rear flanges of the main body into the screw posts on the rear panel. Hand-tight only — overtightening will split the printed posts. If a screw feels gritty going in, back out and re-start; you're cross-threading.

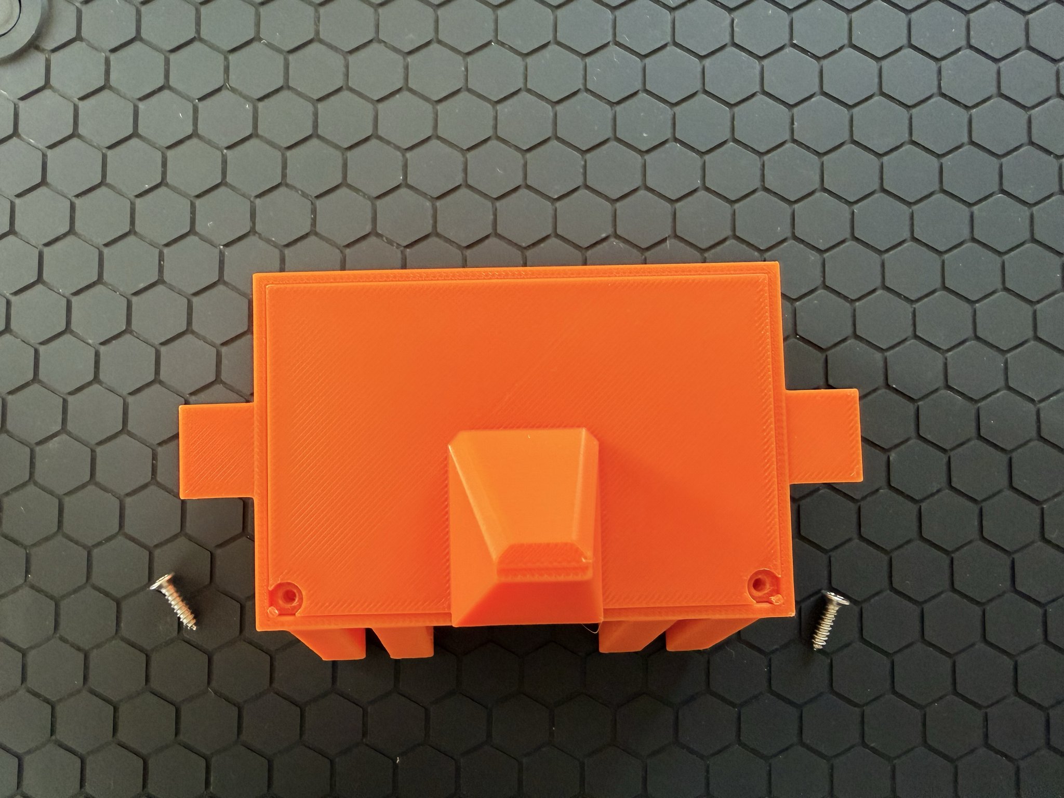
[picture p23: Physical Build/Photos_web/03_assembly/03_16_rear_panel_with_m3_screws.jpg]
Rear panel + screws ready


Done.

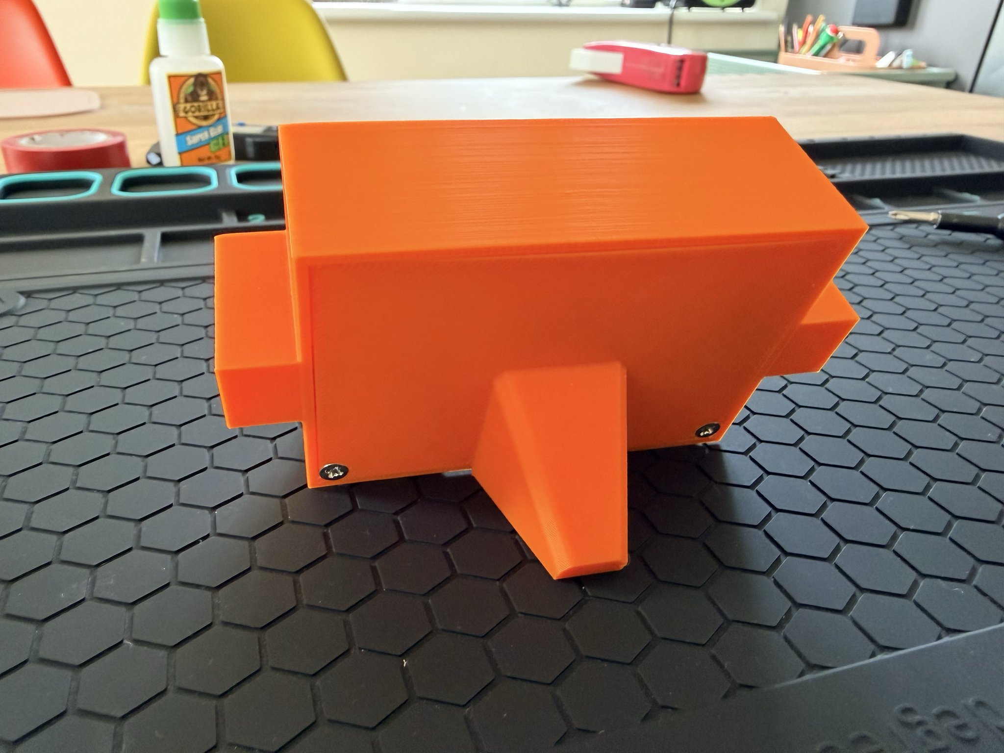
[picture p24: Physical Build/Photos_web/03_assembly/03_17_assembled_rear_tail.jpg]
Assembled — rear with tail


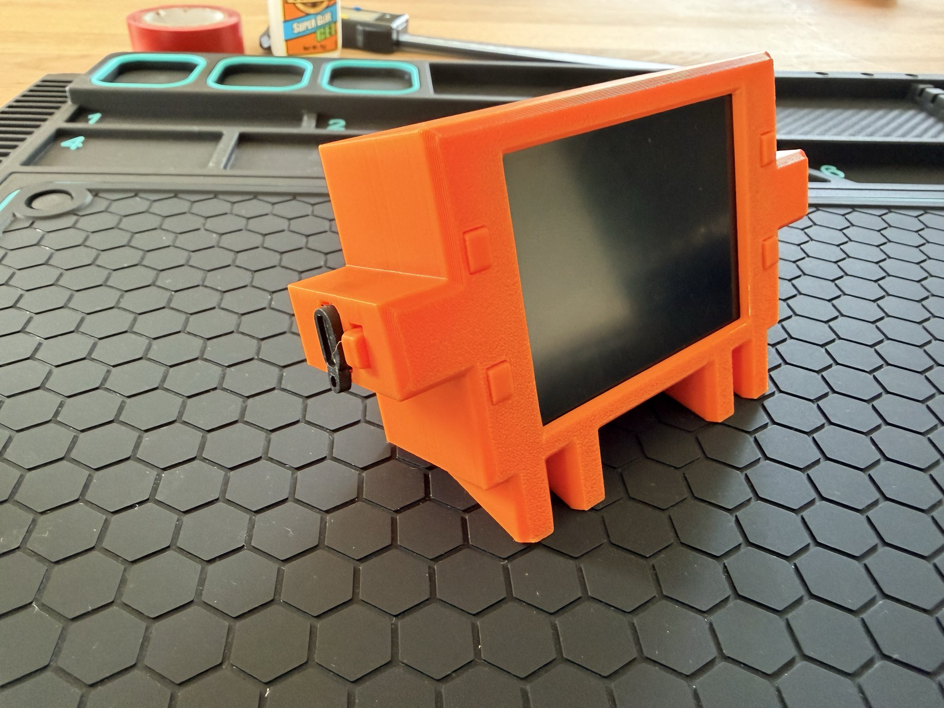
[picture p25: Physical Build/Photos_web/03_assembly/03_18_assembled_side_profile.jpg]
Assembled — side profile


---

## 6. First power-on from the case

Plug in USB, or press the SHIM power button if the battery is charged.

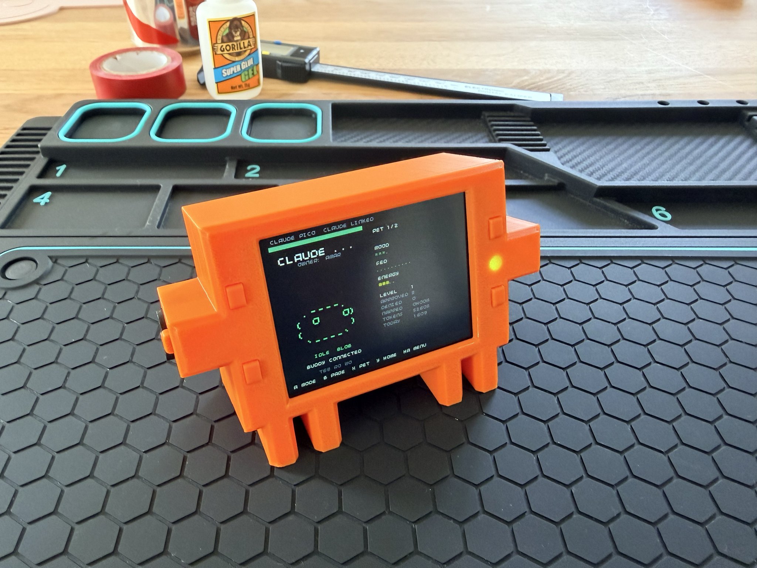
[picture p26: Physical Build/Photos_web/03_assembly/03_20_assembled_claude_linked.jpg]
Powered on — Claude home


`A` / `B` step through screens, `X` / `Y` jump to Pet and Home. `Hold A` opens settings, `Hold Y` puts the buddy to sleep. Full reference: [../README.md#controls](../README.md).

---

## 7. Troubleshooting

If the build came up clean on first power-on, you're done. The rest of this section is for when it doesn't.

### The smoke-test ladder

The firmware ships as three UF2s in increasing complexity. If the full firmware misbehaves, walk down the ladder until you find the first one that works — that tells you which layer is broken.

- `claude_buddy_pico_smoke.uf2` — just the hardware. Display, buttons, VSYS, USB sense, uptime.
- `claude_buddy_ble_smoke.uf2` — adds the BLE radio and protocol.
- `claude_buddy_pico.uf2` — the full firmware.

Flash the same way as the main firmware. The hardware smoke test should show `CLAUDE BUDDY PICO SMOKE TEST`, a non-zero `VSYS` reading, `USB SENSE: ON`, an uptime counter, and per-button `HIT` indicators when you press `A` / `B` / `X` / `Y`.

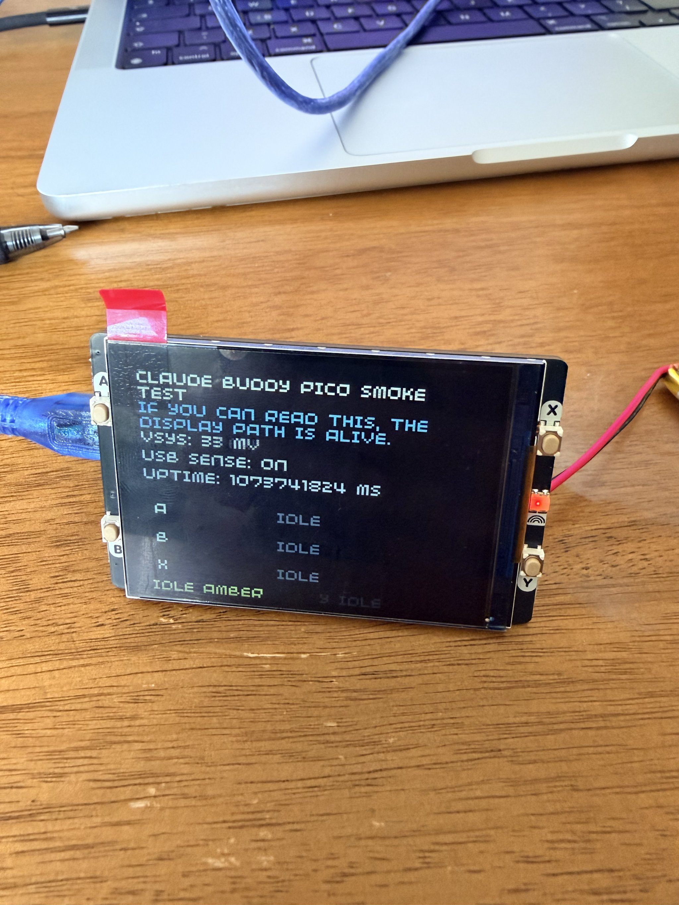
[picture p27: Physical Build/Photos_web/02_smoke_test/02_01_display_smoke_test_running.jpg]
Hardware smoke test running


The BLE smoke test should show `ADVERTISING` and a name field of `Claude Pico`.

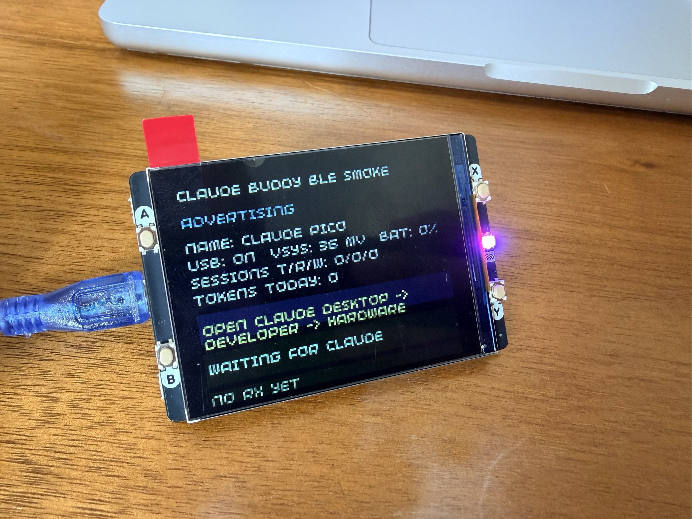
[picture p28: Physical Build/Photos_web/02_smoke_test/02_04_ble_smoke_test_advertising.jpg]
BLE smoke test, advertising


### Specific failures

- **`BOOTSEL` recovery is flaky with the battery attached.** Known LiPo SHIM behaviour, not a firmware bug. Either disconnect the battery before reflashing, or use the battery-connected sequence: plug USB, hold `BOOTSEL`, also hold the SHIM side button near the USB end, wait for the `RP2350` volume.
- **Display shows garbage after flashing.** Re-flash the hardware smoke test. If that's also broken, the headers between Pico and display aren't making clean contact. Re-seat the stack.
- **Pairs but never gets past `ADVERTISING`.** Developer Mode off in Claude Desktop, or you're on a Claude Desktop build that doesn't expose Hardware Buddy yet. Not a firmware problem.
- **Battery feels warm.** Disconnect immediately. Inspect SHIM solder for bridges around `VBUS` / `VSYS` / `3V3`. Don't reconnect until you've found the bridge.
- **Buttons sticky after assembly.** Case walls shaving the printed stems. Open up, sand stems with 400-grit, reinstall.

---

## 8. What to do next

- **Build the minimum version first** if you're unsure — Pico 2 W + Display Pack + USB cable. That tells you whether the firmware works on your hardware before you commit to the SHIM solder.
- **Open the `.step` files** in Fusion / FreeCAD / Onshape if you want to improve the case. The USB cutout, battery retainer, and button stems are the obvious next passes.
- **Post your build.** Photos and fit notes from different prints, batteries, and cable setups help the next builder.

---

## Credits and licence

- Upstream BLE Hardware Buddy protocol: [anthropics/claude-desktop-buddy](https://github.com/anthropics/claude-desktop-buddy). The original project is Felix Rieseberg's.
- Pico firmware port, case design, build notes: this repo.
- Mascot: Claude Code mascot (Anthropic).
- Licence: see [../LICENSE](../LICENSE).

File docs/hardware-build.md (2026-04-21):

# Hardware Build

## Parts

Exact prototype parts:

- `Raspberry Pi Pico 2 W` with headers
- `Pimoroni Pico Display Pack 2.8` (`PIM715`)
- `Pimoroni LiPo SHIM for Pico` (`PIM557`)
- `Pimoroni 2000mAh LiPo` (`BAT0005`)
- micro-USB data cable
- soldering iron, solder, and ideally a multimeter

## Assembly Order

1. Dry-fit the `Pico 2 W` into the `Display Pack 2.8` with no battery attached.
2. Remove the display and mount the `LiPo SHIM` to the back of the Pico.
3. Prefer the back-to-back SHIM method first. The display's underside connector makes the sandwich stack tight with short header pins.
4. Inspect the SHIM solder joints closely before applying power.
5. Refit the Pico into the display board.
6. Power the board from USB only for the first bring-up.
7. Connect the battery only after the USB-only power-up succeeds.

## Power Pins To Double-Check

Before first power, inspect around:

- `VBUS`
- `VSYS`
- `3V3_EN`
- `3V3`

On this build the hardware risk was mechanical fit and accidental solder bridges, not logic-level compatibility.

## Battery And Antenna Notes

- Keep the LiPo away from the Pico 2 W antenna end.
- Avoid metal hardware near the antenna keep-out area.
- Keep sharp case edges and screw posts away from the battery pouch.
- Treat the LiPo SHIM button as hardware-only power control, not an app button.

## BOOTSEL Recovery That Actually Worked

With the battery connected, the Pico often stayed powered in a way that made normal `BOOTSEL` recovery unreliable.

The most reliable fallback reflash workflow for this exact prototype was:

1. Disconnect the battery from the LiPo SHIM.
2. Hold the Pico `BOOTSEL` button.
3. Plug USB into the Mac.
4. Wait for the `RP2350` volume to appear.
5. Flash the new UF2.
6. Reconnect the battery after the board is running again if needed.

There was also a battery-connected path that worked on this build:

1. Leave the battery connected.
2. Plug USB into the Mac first.
3. Hold the Pico `BOOTSEL` button.
4. While holding `BOOTSEL`, press and hold the LiPo SHIM side button near the USB end.
5. Wait for the `RP2350` volume to appear.

So the practical guidance is:

- use the battery-disconnect method as the safest fallback
- if you want to recover without unplugging the battery, try `USB first -> hold BOOTSEL -> hold SHIM side button`

## First Power-Up Checklist

- nothing gets hot
- display lights cleanly
- the Pico enumerates over USB
- button presses register
- RGB LED responds

If any of those fail, stop before connecting the battery.

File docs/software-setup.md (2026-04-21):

# Software Setup

## Build Tooling On macOS

Install the local toolchain and helper apps:

```bash
scripts/bootstrap_macos.sh
```

That setup expects:

- `cmake`
- `ninja`
- `picotool`
- an Arm embedded GCC toolchain

If Homebrew's default embedded compiler is missing `nosys.specs` on your machine, use the workspace-local fallback:

```bash
scripts/extract_local_toolchain.sh
```

## Clone Vendor Dependencies

```bash
scripts/clone_deps.sh
```

Expected directories:

- `third_party/pico-sdk`
- `third_party/pico-examples`
- `third_party/pimoroni-pico`
- `third_party/pimoroni-pico-rp2350`

## Configure And Build

```bash
scripts/configure_firmware.sh
cmake --build build/pico
```

Main outputs:

- `build/pico/claude_buddy_pico.uf2`
- `build/pico/claude_buddy_pico_smoke.uf2`
- `build/pico/claude_buddy_ble_smoke.uf2`

## Flashing

The safest fallback workflow on this prototype was:

1. Disconnect the battery.
2. Hold `BOOTSEL`.
3. Plug USB into the Mac.
4. Wait for `RP2350` to mount.
5. Copy the UF2.

There was also a battery-connected method that worked on this hardware:

1. Leave the battery connected.
2. Plug USB into the Mac first.
3. Hold `BOOTSEL`.
4. While holding `BOOTSEL`, press and hold the LiPo SHIM side button near the USB end.
5. Wait for `RP2350` to mount.

Example:

```bash
cp build/pico/claude_buddy_pico.uf2 /Volumes/RP2350/
```

## Firmware Targets

### `claude_buddy_pico_smoke`

Use this first when you only want to verify:

- screen draw
- A/B/X/Y buttons
- RGB LED
- USB / VSYS readings

### `claude_buddy_ble_smoke`

Use this when debugging:

- BLE discovery
- passkey pairing
- Claude Desktop connection
- Buddy `status` payload shape

### `claude_buddy_pico`

Use this for the real Pico Buddy firmware:

- Buddy UI
- secure pairing flow
- approvals
- demo mode
- dock clock
- flash-backed settings/stats
- single installed pushed character pack

## Claude Desktop Pairing

1. Turn on Developer Mode in Claude Desktop.
2. Open `Developer -> Open Hardware Buddy...`
3. Click `Connect`
4. Select `Claude Pico`
5. Complete the passkey flow if prompted

The Claude Desktop `Name` field changes the large device name shown on the Pico. The smaller owner label comes from the Buddy `owner` value that Claude Desktop or the bridge sends.

On-device settings are available with `Hold A`.

For the full on-device UI walkthrough, see [user-guide.md](user-guide.md).

If the Hardware Buddy menu is hidden on a Claude Desktop build, verify the app feature exposure first before assuming the Pico firmware is at fault.

## Hardware-Specific Notes

- Final firmware targets `pico2_w`.
- Battery sampling uses `GPIO29 / ADC3` for `VSYS`.
- USB presence uses CYW43 `WL GPIO 2`.
- The display RGB LED pin mapping in docs vs code has been inconsistent historically, so test it on-device rather than trusting old snippets.

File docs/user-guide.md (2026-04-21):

# User Guide

This guide explains the on-device UI for the main firmware target: `claude_buddy_pico`.

## Quick Start

After the Pico boots, the UI is split into three areas:

- left column: Buddy name, owner, animated pet, current state, and a short status banner
- right panel: the current screen content
- footer: the active button hints

The main screens cycle like this:

1. `Home`
2. `Pet`
3. `Info`

Tap `A` to move to the next main screen.

## Button Map

- `A`: next main screen, approve prompt, advance selection in overlays
- `B`: next page, next transcript chunk, deny prompt, or confirm selection in overlays
- `X`: next pet normally, raw prompt details during approvals
- `Y`: home / back
- `Hold A`: open or close the main menu
- `Hold X`: trigger the one-shot `dizzy` easter egg
- `Hold Y`: nap / wake
- `LiPo SHIM button`: hardware-only power control, never app input

The footer always shows the active controls for the current context.

## Home Screen

The `Home` screen is the main live status view.

The left column shows:

- the large Buddy device name
- the smaller owner label
- the animated pet
- the current Buddy state and selected pet
- a short banner such as `Buddy connected`, `Claude is working`, or `Approval pending`
- the summary counters `T / R / W` for total, running, and waiting

The right panel shows:

- connection chip: `secure`, `pairing`, or `idle`
- power chip: battery percent plus `usb` or `bat`
- `sessions`
- `running`
- `waiting`
- `today`
- transcript or recent message content

If more transcript lines exist than fit on screen, the panel shows `B more X/Y`. Press `B` to page through transcript chunks. When new lines arrive from Claude, the transcript pager resets to the newest chunk automatically.

If transcript display is turned off in settings, the `Home` screen still shows the current message and latest ack line.

## Pet Screen

The `Pet` screen has two pages. Press `B` to switch between them.

Page 1 shows live pet stats:

- `mood`
- `fed`
- `energy`
- `level`
- `approved`
- `denied`
- `napped`
- `tokens`
- `today`

Page 2 explains what drives those stats:

- fast approvals improve mood
- more tokens increase feed and level progress
- naps refill energy
- reminder text for the main controls

## Info Screen

The `Info` screen has seven pages. Press `B` to move through them.

The pages are:

1. `About`
2. `Buttons`
3. `States`
4. `Claude`
5. `Device`
6. `Bluetooth`
7. `Build`

These pages act as the built-in on-device reference manual.

## Prompt Overlay

When Claude asks for a permission decision, a centered `APPROVAL` overlay appears over the normal UI.

The overlay shows:

- how long the prompt has been waiting
- the tool name when available
- either a short human-readable prompt hint or the raw JSON payload

Prompt controls:

- `A`: approve once
- `B`: deny
- `X`: toggle raw details
- `Y`: return the underlying display mode to `Home`

If a decision has already been sent, the prompt overlay shows `sent...` until the next heartbeat clears or replaces that prompt.

## Main Menu

Open the main menu with `Hold A`.

Menu items:

- `settings`: opens the settings overlay
- `screen off`: turns the screen off until the next button wake
- `help`: jumps to the `Info -> Buttons` page
- `about`: jumps to the `Info -> About` page
- `demo: on/off`: toggles demo mode
- `close`: closes the menu

Overlay navigation is consistent:

- `A`: move selection
- `B`: choose
- `Y`: back

## Settings

Open `Settings` from the main menu.

Settings items:

- `bright: 0/4` to `4/4`
- `led: on/off`
- `transcript: on/off`
- `demo: on/off`
- `dock clock: on/off`
- `pet: <species>`
- `reset`
- `back`

What each setting does:

- `bright`: cycles through five backlight steps. `4/4` is the brightest normal setting.
- `led`: enables or disables the RGB status LED.
- `transcript`: shows or hides wrapped transcript lines on the `Home` screen.
- `demo`: runs a local fake heartbeat sequence for showing the device without Claude Desktop driving it.
- `dock clock`: allows the dock clock view to appear when the Buddy is idle on USB power and has already received a time sync.
- `pet`: cycles through the built-in pets, or the currently installed custom pack if one exists.
- `reset`: opens the reset overlay.
- `back`: closes settings.

All of these settings are persisted in flash.

## Reset Overlay

The reset overlay contains:

- `delete char`
- `factory reset`
- `back`

Reset actions use a two-step confirm flow:

1. first `B` press arms the selected action for a short window
2. second `B` press while still armed performs it

What each reset action does:

- `delete char`: removes the installed custom character pack
- `factory reset`: clears device settings and stats, resets the active pet selection, clears stored identity fields, and drops the current bond when connected
- `back`: exits reset

## Dock Clock

The dock clock is a Pico-specific idle screen.

It only appears when all of these are true:

- the display mode is `Home`
- `dock clock` is enabled in settings
- USB power is present
- a time sync has already been received
- no prompt or overlay is active
- demo mode is off
- the Buddy is linked and idle

When the dock clock is showing:

- the right panel displays `HH:MM`
- the date appears underneath
- the owner name or `USB dock mode` is shown below the clock
- `B` is not used for transcript paging on this screen

## Nap, Screen Off, And Wake

`Hold Y` toggles nap mode.

While napping:

- the pet state becomes `sleep`
- the banner changes to `Buddy is napping`
- the backlight drops to a low glow
- any normal button press wakes the Buddy

`screen off` from the main menu is different from nap:

- it turns the backlight fully off
- the next button press wakes the screen
- it does not count as nap time

The firmware also dims automatically after inactivity and can turn the screen fully off after a longer idle period while on battery.

## Names And Identity

There are two user-visible identity fields:

- large device name: the Buddy `name`
- smaller owner line: the Buddy `owner`

How they are set:

- the Claude Desktop Hardware Buddy `Name` field changes the large on-device name
- the Buddy `owner` value sent by Claude Desktop or the bridge changes the smaller owner line

So another builder will see their own chosen values, not the names used during bring-up on this machine.

## LED Meanings

The display RGB LED is intentionally driven below full power so it is visible without being harsh in a dark room.

Current LED map:

- `off`: asleep or not linked
- `green`: linked and idle
- `blue`: Claude is running work
- `amber`: approval pending
- `magenta`: pairing or character install
- `red`: low battery

If `led` is turned off in settings, the LED stays off regardless of Buddy state.

## Character Packs

This Pico port supports:

- built-in ASCII pets compiled into firmware
- one installed pushed character pack stored in flash

When a character pack is being installed:

- the right panel changes to an install progress view
- the left banner shows `Installing character pack`
- the LED uses the pairing/install color

The current renderer supports pushed `text` manifests on-device. The wire protocol for `char_begin`, `file`, `chunk`, `file_end`, and `char_end` is implemented, but GIF-pack rendering from the original ESP32 sample is still future work.

For a ready-to-send sample folder, use [../examples/character-packs/sunset_blob](../examples/character-packs/sunset_blob).

## Status Messages You Will Commonly See

Examples of normal status text:

- `Waiting for Claude Desktop`
- `Connected, pairing in progress`
- `Buddy connected`
- `Claude is working`
- `Claude needs attention`
- `Approval pending`
- `Installing character pack`
- `Demo mode`
- `Buddy is napping`

These messages come from the firmware state machine and are meant to be the fastest way to understand what the device is doing.

## Everyday Usage Flow

For a normal day-to-day flow:

1. Power the Pico and let it reconnect to Claude Desktop.
2. Stay on `Home` for live activity and transcript.
3. Use `A` to move to `Pet` or `Info`.
4. Use `B` to page transcript or move through screen sub-pages.
5. Use `X` to swap pets.
6. Use `Hold A` for settings or demo mode.
7. Use `Hold Y` when you want the Buddy to nap.
8. Respond to approvals with `A` or `B` when prompts appear.

## Related Docs

- [README.md](../README.md)
- [software-setup.md](software-setup.md)
- [folder-push.md](folder-push.md)
- [protocol-map.md](protocol-map.md)
- [feature-matrix.md](feature-matrix.md)

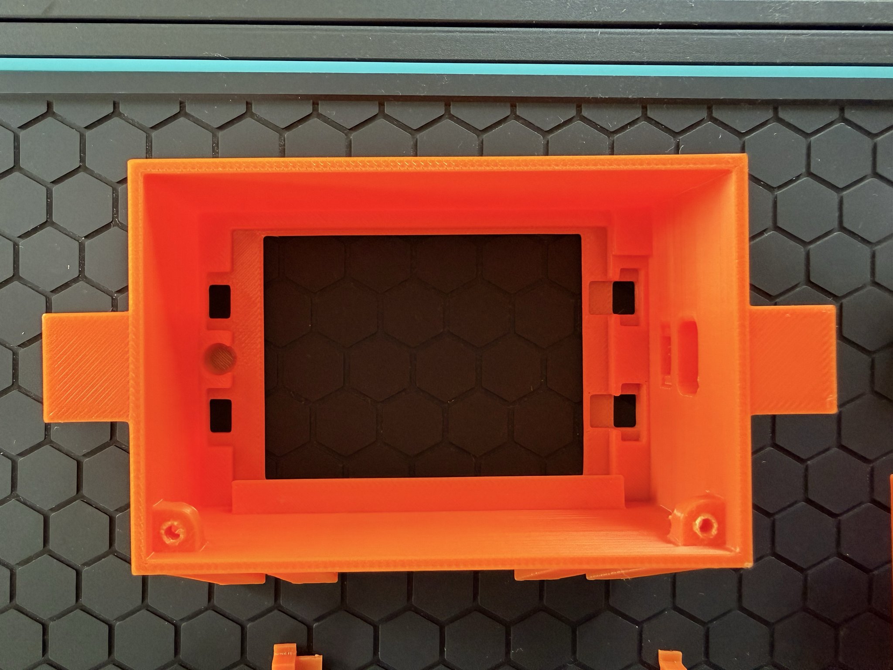
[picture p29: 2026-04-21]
Physical Build/Photos_web/03_assembly/03_08_main_body_empty_front.jpg

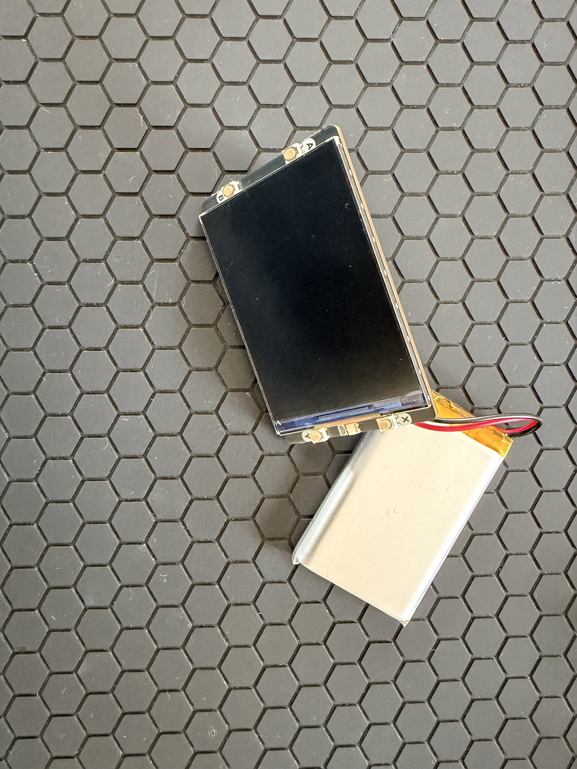
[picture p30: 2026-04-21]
Physical Build/Photos_web/03_assembly/03_01_display_battery_prep.jpg

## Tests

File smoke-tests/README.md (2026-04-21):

# Smoke Test Plan

Use MicroPython first for the shortest hardware bring-up loop, then switch to the C++ firmware for the full BLE device.

## Firmware to Flash

- Use the RP2350-specific Pimoroni build for `rpi-pico2_w`.
- Do not use the older RP2040-only Pimoroni MicroPython builds for this board.

## Smoke Test Checklist

1. Draw text and a color fill on the Pico Display Pack 2.8.
2. Confirm all four front buttons read correctly.
3. Run a separate RGB LED test before relying on any LED pin mapping.
4. Verify battery voltage through `GPIO29 / ADC3`.
5. Verify USB presence through CYW43 `WL GPIO 2`.

## Battery Notes

- Sample VSYS periodically, not constantly.
- Treat the older Pico and Pico W `GP24` examples as historical reference only.
- Do the first boot over USB before connecting the battery.

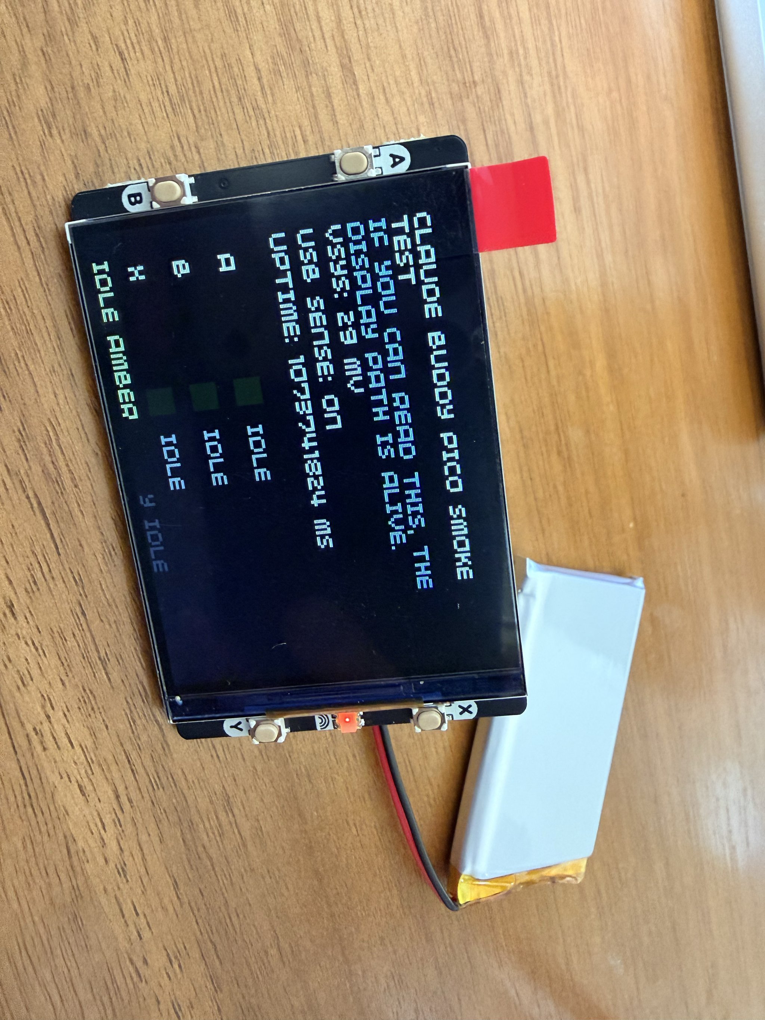
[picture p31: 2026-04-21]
Physical Build/Photos_web/02_smoke_test/02_03_display_smoke_test_closeup.jpg

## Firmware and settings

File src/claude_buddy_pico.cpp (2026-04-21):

// claude_buddy_pico.cpp
//
// Pico Buddy main firmware.
//
// This file stays as a single translation unit so BLE, persistence, UI state,
// and input handling can be debugged together on real hardware. Navigate by
// section: constants, state, storage helpers, BLE event handlers, UI
// rendering, and the main loop.

#include <algorithm>
#include <cinttypes>
#include <ctime>
#include <cstdio>
#include <cstdlib>
#include <cstring>
#include <string>

#include "btstack.h"
#include "btstack_base64_decoder.h"
#include "ble/gatt-service/nordic_spp_service_server.h"

#include "buddy.h"
#include "button.hpp"
#include "drivers/st7789/st7789.hpp"
#include "hardware/adc.h"
#include "hardware/flash.h"
#include "libraries/pico_graphics/pico_graphics.hpp"
#include "pico/btstack_flash_bank.h"
#include "pico/cyw43_arch.h"
#include "pico/flash.h"
#include "pico/stdlib.h"
#include "pico/time.h"
#include "pico_display_28.hpp"
#include "rgbled.hpp"

#include "claude_buddy_pico.h"

#if BUDDY_UI_V2
#include "ui_v2/ui_core.h"
#include "ui_v2/permissions_log.h"
#include "ui_v2/ui_state.h"
#endif

using namespace pimoroni;

namespace {

constexpr uint32_t kUiTickMs = 40;
constexpr uint32_t kBatterySampleMs = 2000;
constexpr uint32_t kPromptKeepAliveMs = 30000;
constexpr uint32_t kDimAfterMs = 20000;
constexpr uint32_t kScreenOffAfterMs = 30000;
constexpr uint32_t kHoldThresholdMs = 800;
constexpr float kAdcReferenceVolts = 3.3f;
constexpr float kVoltageDividerScale = 3.0f;
constexpr uint32_t kDefaultPasskey = 123456;
constexpr uint32_t kTokensPerLevel = 50000;
constexpr uint32_t kDemoStepMs = 8000;
constexpr uint32_t kStorageOffset = PICO_FLASH_SIZE_BYTES - FLASH_SECTOR_SIZE;
constexpr uint32_t kPersistDebounceMs = 2000;
constexpr uint32_t kStorageMagic = 0x43425032;
constexpr uint16_t kStorageVersion = 5;
constexpr uint8_t kCustomSpeciesSentinel = 0xff;
constexpr uint8_t kInfoPageCount = 7;
constexpr uint8_t kPetPageCount = 2;
constexpr uint8_t kMenuCount = 6;
constexpr uint8_t kSettingsCount = 8;
constexpr uint8_t kResetCount = 3;

constexpr int kLeftX = 8;
constexpr int kLeftY = 12;
constexpr int kLeftW = 140;
constexpr int kLeftH = 212;
constexpr int kRightX = 156;
constexpr int kRightY = 12;
constexpr int kRightW = 156;
constexpr int kRightH = 212;
constexpr int kFooterY = 226;

constexpr uint16_t C_BG = 0x0000;
constexpr uint16_t C_PANEL = 0x18C3;
constexpr uint16_t C_PANEL_ALT = 0x2104;
constexpr uint16_t C_TEXT = 0xFFFF;
constexpr uint16_t C_DIM = 0x8410;
constexpr uint16_t C_HOT = 0xFA20;
constexpr uint16_t C_GREEN = 0x07E0;
constexpr uint16_t C_BLUE = 0x041F;
constexpr uint16_t C_GOLD = 0xFFE0;
constexpr uint16_t C_WHITE = 0xFFFF;
constexpr uint8_t kLedMax = 72;
constexpr char kDefaultDeviceName[] = "Claude Pico";

constexpr uint8_t kBrightnessLevels[] = {48, 88, 128, 176, 220};

static_assert(kStorageOffset + FLASH_SECTOR_SIZE <= PICO_FLASH_SIZE_BYTES, "Persistent storage must fit in flash");
static_assert(kStorageOffset >= PICO_FLASH_BANK_STORAGE_OFFSET + PICO_FLASH_BANK_TOTAL_SIZE,
              "Persistent storage must not overlap BTstack flash bank");

enum PersonaState : uint8_t {
  P_SLEEP,
  P_IDLE,
  P_BUSY,
  P_ATTENTION,
  P_CELEBRATE,
  P_DIZZY,
  P_HEART,
};

enum class FaceMotionProfile : uint8_t {
  Full = 0,
  Reduced = 1,
  Static = 2,
};

enum class FaceRenderStyle : uint8_t {
  Classic = 0,
  Hybrid = 1,
  Mascot = 2,
};

enum class PromptResultState : uint8_t {
  None = 0,
  Approved = 1,
  Denied = 2,
  TimedOut = 3,
};

enum class PromptResultSpeed : uint8_t {
  None = 0,
  Quick = 1,
  Normal = 2,
  Slow = 3,
};

enum class PowerEventState : uint8_t {
  None = 0,
  UsbPlug = 1,
  UsbUnplug = 2,
};

enum class DisplayMode : uint8_t {
  Normal,
  Pet,
  Info,
};

const char* state_names[] = {"sleep", "idle", "busy", "attention", "celebrate", "dizzy", "heart"};

struct DemoScenario {
  const char* name;
  uint32_t total;
  uint32_t running;
  uint32_t waiting;
  bool completed;
  uint32_t tokens_today;
  const char* msg;
  const char* entries[4];
  uint8_t entry_count;
};

const DemoScenario demo_scenarios[] = {
    {"asleep", 0, 0, 0, false, 0, "Demo: waiting for Claude", {"dock mode idle"}, 1},
    {"idle", 1, 0, 0, false, 12000, "Demo: all clear", {"workspace calm", "ready to help"}, 2},
    {"busy", 4, 3, 0, false, 89000, "Demo: Claude is working", {"reading files", "running tools", "writing code"}, 3},
    {"attention", 2, 1, 1, false, 45000, "Demo: approval pending", {"tool wants access", "A approve, B deny"}, 2},
    {"celebrate", 5, 0, 0, true, 142000, "Demo: task wrapped up", {"tests passed", "tokens milestone"}, 2},
};

struct PersistentBlobV3 {
  uint32_t magic;
  uint16_t version;
  uint16_t size;
  uint8_t brightness_level;
  uint8_t led_enabled;
  uint8_t transcript_enabled;
  uint8_t demo_mode;
  uint8_t clock_enabled;
  uint8_t ascii_species_idx;
  uint8_t custom_selected;
  // Face animation gate. Claimed from the old `reserved0` slot. Polarity
  // is *inverted* on purpose: 0 = animated (default), 1 = static. That way
  // v3 blobs — which wrote reserved0=0 — load as "animated on" rather
  // than making every existing user look like their buddy lost its soul
  // on first upgrade. `state.motion_profile = (face_disabled == 0) ? Full : Static`.
  // When we bump kStorageVersion next, we can flip to positive polarity.
  uint8_t face_disabled;
  char device_name[32];
  char owner[32];
  uint32_t approvals;
  uint32_t denials;
  uint32_t nap_seconds;
  uint32_t tokens_total;
  uint32_t level;
  uint16_t velocity[8];
  uint8_t vel_idx;
  uint8_t vel_count;
  uint8_t custom_valid;
  uint8_t reserved1;
  PackDefinition custom_pack;
  uint32_t crc;
};

struct PersistentBlobV4 {
  uint32_t magic;
  uint16_t version;
  uint16_t size;
  uint8_t brightness_level;
  uint8_t led_enabled;
  uint8_t transcript_enabled;
  uint8_t demo_mode;
  uint8_t clock_enabled;
  uint8_t ascii_species_idx;
  uint8_t custom_selected;
  uint8_t face_disabled;
  char device_name[32];
  char owner[32];
  uint32_t approvals;
  uint32_t denials;
  uint32_t nap_seconds;
  uint32_t tokens_total;
  uint32_t level;
  uint8_t pet_fed_pct;
  uint8_t pet_energy_pct;
  uint16_t pet_feeds;
  uint16_t pet_plays;
  uint16_t reserved2;
  uint32_t pet_age_minutes;
  uint16_t velocity[8];
  uint8_t vel_idx;
  uint8_t vel_count;
  uint8_t custom_valid;
  uint8_t reserved1;
  PackDefinition custom_pack;
  uint32_t crc;
};

struct PersistentBlob {
  uint32_t magic;
  uint16_t version;
  uint16_t size;
  uint8_t brightness_level;
  uint8_t led_enabled;
  uint8_t transcript_enabled;
  uint8_t demo_mode;
  uint8_t clock_enabled;
  uint8_t ascii_species_idx;
  uint8_t custom_selected;
  uint8_t motion_profile;
  uint8_t face_style;
  char device_name[32];
  char owner[32];
  uint32_t approvals;
  uint32_t denials;
  uint32_t nap_seconds;
  uint32_t tokens_total;
  uint32_t level;
  uint8_t pet_fed_pct;
  uint8_t pet_energy_pct;
  uint16_t pet_feeds;
  uint16_t pet_plays;
  uint16_t reserved2;
  uint32_t pet_age_minutes;
  uint16_t velocity[8];
  uint8_t vel_idx;
  uint8_t vel_count;
  uint8_t custom_valid;
  uint8_t reserved1;
  PackDefinition custom_pack;
  uint32_t crc;
};

ST7789 st7789(PicoDisplay28::WIDTH, PicoDisplay28::HEIGHT, ROTATE_0, false, get_spi_pins(BG_SPI_FRONT));
PicoGraphics_PenRGB332 graphics(st7789.width, st7789.height, nullptr);
RGBLED led(PicoDisplay28::LED_R, PicoDisplay28::LED_G, PicoDisplay28::LED_B);

Button button_a(PicoDisplay28::A);
Button button_b(PicoDisplay28::B);
Button button_x(PicoDisplay28::X);
Button button_y(PicoDisplay28::Y);

const uint8_t adv_data[] = {
    2, BLUETOOTH_DATA_TYPE_FLAGS, 0x06,
    12, BLUETOOTH_DATA_TYPE_COMPLETE_LOCAL_NAME, 'C', 'l', 'a', 'u', 'd', 'e', ' ', 'P', 'i', 'c', 'o',
};
const uint8_t adv_data_len = sizeof(adv_data);

const uint8_t scan_response_data[] = {
    17, BLUETOOTH_DATA_TYPE_COMPLETE_LIST_OF_128_BIT_SERVICE_CLASS_UUIDS,
    0x9e, 0xca, 0xdc, 0x24, 0x0e, 0xe5, 0xa9, 0xe0, 0x93, 0xf3, 0xa3, 0xb5, 0x01, 0x00, 0x40, 0x6e,
};
const uint8_t scan_response_data_len = sizeof(scan_response_data);

struct BuddyState {
  hci_con_handle_t connection_handle = HCI_CON_HANDLE_INVALID;
  bd_addr_t peer_addr{};
  bd_addr_type_t peer_addr_type = BD_ADDR_TYPE_LE_PUBLIC;

  bool advertising = true;
  bool link_connected = false;
  bool secure = false;
  bool paired = false;
  bool nus_linked = false;
  bool prompt_active = false;
  bool response_sent = false;
  bool prompt_details = false;
  bool transcript_enabled = true;
  bool led_enabled = true;
  bool screen_off = false;
  bool napping = false;
  bool battery_low = false;
  bool usb_present = false;
  bool recently_completed = false;

  bool last_a = false;
  bool last_b = false;
  bool last_x = false;
  bool last_y = false;
  bool a_hold_fired = false;
  bool x_hold_fired = false;
  bool y_hold_fired = false;
  bool demo_mode = false;
  bool clock_enabled = true;
  FaceMotionProfile motion_profile = FaceMotionProfile::Full;
  FaceRenderStyle face_style = FaceRenderStyle::Hybrid;
  bool rtc_valid = false;
  bool xfer_active = false;
  bool xfer_file_open = false;
  bool xfer_capture_manifest = false;

  DisplayMode display_mode = DisplayMode::Normal;
  PersonaState base_state = P_SLEEP;
  PersonaState active_state = P_SLEEP;

  uint8_t security_level = 0;
  uint8_t brightness_level = 4;
  uint8_t battery_percent = 0;
  uint8_t info_page = 0;
  uint8_t pet_page = 0;
  uint8_t msg_scroll = 0;
  uint8_t line_count = 0;
  uint8_t vel_idx = 0;
  uint8_t vel_count = 0;
  uint8_t energy_at_nap = 3;
  uint8_t pet_fed_pct = 80;
  uint8_t pet_energy_pct = 70;
  uint8_t reset_confirm_idx = 0xff;

  uint16_t battery_mv = 0;
  uint16_t velocity[8]{};
  uint16_t line_gen = 0;
  uint16_t last_line_gen = 0;

  uint32_t reconnects = 0;
  uint32_t approvals = 0;
  uint32_t denials = 0;
  uint32_t nap_seconds = 0;
  uint32_t total = 0;
  uint32_t running = 0;
  uint32_t waiting = 0;
  uint32_t tokens_total = 0;
  uint32_t tokens_today = 0;
  uint32_t level = 0;
  uint32_t prompt_arrived_ms = 0;
  uint32_t prompt_result_started_ms = 0;
  uint32_t prompt_result_until_ms = 0;
  uint32_t one_shot_until_ms = 0;
  uint32_t reset_confirm_until = 0;
  uint32_t last_bridge_tokens = 0;
  uint32_t last_nap_end_ms = 0;
  uint32_t nap_start_ms = 0;
  uint32_t rtc_local_epoch = 0;
  uint32_t rtc_synced_ms = 0;
  uint32_t xfer_expected = 0;
  uint32_t xfer_written = 0;
  uint32_t xfer_total = 0;
  uint32_t xfer_total_written = 0;
  uint32_t persist_due_ms = 0;
  uint32_t pet_age_minutes = 0;
  uint32_t pet_last_decay_ms = 0;
  uint32_t pet_last_persist_ms = 0;
  uint32_t token_rate_window_start_ms = 0;
  uint32_t token_rate_window_start_tokens_today = 0;
  uint16_t token_rate_per_min = 0;
  uint16_t power_event_seq = 0;
  uint8_t prompt_result = 0;
  uint8_t prompt_result_band = 0;
  PowerEventState power_event = PowerEventState::None;

  absolute_time_t connected_since = nil_time;
  absolute_time_t last_heartbeat = nil_time;
  absolute_time_t last_input = nil_time;
  absolute_time_t last_battery_sample = nil_time;
  absolute_time_t a_down_since = nil_time;
  absolute_time_t x_down_since = nil_time;
  absolute_time_t y_down_since = nil_time;

  char status_line[64] = "Advertising";
  char banner[96] = "Waiting for Claude Desktop";
  char msg[96] = "No Claude connected";
  char last_rx[256] = "No RX yet";
  char last_ack[96] = "No acks yet";
  char device_name[32] = "Claude Pico";
  char owner[32] = "";
  char prompt_id[64] = "";
  char prompt_tool[32] = "";
  char prompt_hint[96] = "";
  char passkey[16] = "123456";
  char tx_line[768] = "";
  char xfer_name[24] = "";
  char xfer_file_path[48] = "";
  char lines[8][96]{};
  char manifest_buffer[4096]{};

  bool tx_pending = false;
  bool menu_open = false;
  bool settings_open = false;
  bool reset_open = false;
  bool tokens_synced = false;
  bool persist_dirty = false;
  size_t manifest_len = 0;

  uint8_t menu_sel = 0;
  uint8_t settings_sel = 0;
  uint8_t reset_sel = 0;
  uint16_t pet_feeds = 0;
  uint16_t pet_plays = 0;

  btstack_context_callback_registration_t send_request{};
  btstack_packet_callback_registration_t hci_event_callback_registration{};
  btstack_packet_callback_registration_t sm_event_callback_registration{};
  btstack_timer_source ui_timer{};
} state;

PackDefinition installed_pack{};

uint32_t now_ms() {
  return to_ms_since_boot(get_absolute_time());
}

void copy_string(char* dest, const size_t dest_size, const char* src) {
  if(dest_size == 0) {
    return;
  }
  if(src == nullptr) {
    dest[0] = '\0';
    return;
  }
  std::snprintf(dest, dest_size, "%s", src);
}

void append_ascii_text(char* dest, const size_t dest_size, size_t& len,
                       const char* text) {
  if(dest == nullptr || dest_size == 0 || text == nullptr) {
    return;
  }
  while(*text != '\0' && len + 1 < dest_size) {
    dest[len++] = *text++;
  }
  dest[len] = '\0';
}

void append_ascii_char(char* dest, const size_t dest_size, size_t& len,
                       const char ch) {
  if(dest == nullptr || dest_size == 0 || len + 1 >= dest_size) {
    return;
  }
  dest[len++] = ch;
  dest[len] = '\0';
}

void append_ascii_folded(char* dest, const size_t dest_size, size_t& len,
                         const unsigned char* src, size_t& i,
                         const size_t src_len) {
  const unsigned char ch = src[i];
  if(ch == '\\' && i + 1 < src_len) {
    const unsigned char esc = src[i + 1];
    if(esc == '"' || esc == '\\' || esc == '/') {
      append_ascii_char(dest, dest_size, len, static_cast<char>(esc));
      i += 2;
      return;
    }
    if(esc == 'n' || esc == 'r' || esc == 't') {
      append_ascii_char(dest, dest_size, len, ' ');
      i += 2;
      return;
    }
    if(esc == 'u' && i + 5 < src_len) {
      const char* repl = nullptr;
      if(std::memcmp(src + i + 2, "2014", 4) == 0 || std::memcmp(src + i + 2, "2013", 4) == 0) repl = "-";
      else if(std::memcmp(src + i + 2, "2022", 4) == 0) repl = "*";
      else if(std::memcmp(src + i + 2, "2192", 4) == 0) repl = "->";
      else if(std::memcmp(src + i + 2, "2026", 4) == 0) repl = "...";
      else if(std::memcmp(src + i + 2, "2018", 4) == 0 || std::memcmp(src + i + 2, "2019", 4) == 0) repl = "'";
      else if(std::memcmp(src + i + 2, "201C", 4) == 0 || std::memcmp(src + i + 2, "201D", 4) == 0) repl = "\"";
      else if(std::memcmp(src + i + 2, "00A0", 4) == 0) repl = " ";
      if(repl != nullptr) {
        append_ascii_text(dest, dest_size, len, repl);
      }
      i += 6;
      return;
    }
  }

  if(ch < 0x80) {
    append_ascii_char(dest, dest_size, len,
                      (ch >= 32 || ch == ' ') ? static_cast<char>(ch) : ' ');
    i += 1;
    return;
  }

  if(i + 2 < src_len && ch == 0xE2 && src[i + 1] == 0x80 &&
     (src[i + 2] == 0x94 || src[i + 2] == 0x93)) {
    append_ascii_char(dest, dest_size, len, '-');
    i += 3;
    return;
  }
  if(i + 2 < src_len && ch == 0xE2 && src[i + 1] == 0x80 && src[i + 2] == 0xA2) {
    append_ascii_char(dest, dest_size, len, '*');
    i += 3;
    return;
  }
  if(i + 2 < src_len && ch == 0xE2 && src[i + 1] == 0x86 && src[i + 2] == 0x92) {
    append_ascii_text(dest, dest_size, len, "->");
    i += 3;
    return;
  }
  if(i + 2 < src_len && ch == 0xE2 && src[i + 1] == 0x80 && src[i + 2] == 0xA6) {
    append_ascii_text(dest, dest_size, len, "...");
    i += 3;
    return;
  }
  if(i + 2 < src_len && ch == 0xE2 && src[i + 1] == 0x80 &&
     (src[i + 2] == 0x98 || src[i + 2] == 0x99)) {
    append_ascii_char(dest, dest_size, len, '\'');
    i += 3;
    return;
  }
  if(i + 2 < src_len && ch == 0xE2 && src[i + 1] == 0x80 &&
     (src[i + 2] == 0x9C || src[i + 2] == 0x9D)) {
    append_ascii_char(dest, dest_size, len, '"');
    i += 3;
    return;
  }
  if(i + 1 < src_len && ch == 0xC2 && src[i + 1] == 0xA0) {
    append_ascii_char(dest, dest_size, len, ' ');
    i += 2;
    return;
  }

  append_ascii_char(dest, dest_size, len, '?');
  if((ch & 0xE0u) == 0xC0u && i + 1 < src_len) {
    i += 2;
  } else if((ch & 0xF0u) == 0xE0u && i + 2 < src_len) {
    i += 3;
  } else if((ch & 0xF8u) == 0xF0u && i + 3 < src_len) {
    i += 4;
  } else {
    i += 1;
  }
}

const char* extract_ascii_json_string(const char* start, char* out,
                                      const size_t out_size) {
  size_t len = 0;
  out[0] = '\0';
  const auto* src = reinterpret_cast<const unsigned char*>(start);
  const size_t src_len = std::strlen(start);
  size_t i = 0;
  while(i < src_len && src[i] != '"') {
    append_ascii_folded(out, out_size, len, src, i, src_len);
  }
  out[len] = '\0';
  return (i < src_len && src[i] == '"') ? (start + i + 1) : (start + i);
}

void safe_name_copy(char* dest, const size_t dest_size, const char* src) {
  if(dest_size == 0) {
    return;
  }
  size_t j = 0;
  if(src != nullptr) {
    for(size_t i = 0; src[i] != '\0' && j < dest_size - 1; ++i) {
      const char c = src[i];
      if(c != '"' && c != '\\' && static_cast<unsigned char>(c) >= 0x20) {
        dest[j++] = c;
      }
    }
  }
  dest[j] = '\0';
}

void copy_summary(char* dest, const size_t dest_size, const char* src) {
  if(dest_size == 0) {
    return;
  }
  if(src == nullptr) {
    dest[0] = '\0';
    return;
  }
  std::snprintf(dest, dest_size, "%.250s", src);
}

uint32_t fnv1a32(const void* data, const size_t size) {
  const auto* bytes = static_cast<const uint8_t*>(data);
  uint32_t hash = 2166136261u;
  for(size_t i = 0; i < size; ++i) {
    hash ^= bytes[i];
    hash *= 16777619u;
  }
  return hash;
}

uint16_t parse_hex_color(const char* text, const uint16_t fallback) {
  if(text == nullptr || text[0] == '\0') {
    return fallback;
  }
  const char* cursor = text[0] == '#' ? text + 1 : text;
  char* end = nullptr;
  const uint32_t value = std::strtoul(cursor, &end, 16);
  if(end == cursor) {
    return fallback;
  }
  return static_cast<uint16_t>((((value >> 19) & 0x1f) << 11) | (((value >> 10) & 0x3f) << 5) | ((value >> 3) & 0x1f));
}

const char* skip_ws(const char* cursor) {
  while(cursor != nullptr && (*cursor == ' ' || *cursor == '\n' || *cursor == '\r' || *cursor == '\t')) {
    ++cursor;
  }
  return cursor;
}

const char* find_key(const char* scope, const char* key) {
  if(scope == nullptr || key == nullptr) {
    return nullptr;
  }
  char needle[48];
  std::snprintf(needle, sizeof(needle), "\"%s\"", key);
  const char* found = std::strstr(scope, needle);
  if(found == nullptr) {
    return nullptr;
  }
  const char* colon = std::strchr(found + std::strlen(needle), ':');
  if(colon == nullptr) {
    return nullptr;
  }
  return skip_ws(colon + 1);
}

const char* find_matching(const char* start, const char open_char, const char close_char) {
  if(start == nullptr || *start != open_char) {
    return nullptr;
  }
  int depth = 0;
  bool in_string = false;
  bool escaped = false;
  for(const char* cursor = start; *cursor != '\0'; ++cursor) {
    const char ch = *cursor;
    if(in_string) {
      if(escaped) {
        escaped = false;
      } else if(ch == '\\') {
        escaped = true;
      } else if(ch == '"') {
        in_string = false;
      }
      continue;
    }
    if(ch == '"') {
      in_string = true;
      continue;
    }
    if(ch == open_char) {
      ++depth;
    } else if(ch == close_char) {
      --depth;
      if(depth == 0) {
        return cursor;
      }
    }
  }
  return nullptr;
}

bool extract_string_value(const char* scope, const char* key, char* out, const size_t out_size) {
  const char* value = find_key(scope, key);
  if(value == nullptr || *value != '"' || out == nullptr || out_size == 0) {
    return false;
  }
  ++value;
  size_t length = 0;
  bool escaped = false;
  while(*value != '\0' && length + 1 < out_size) {
    if(escaped) {
      out[length++] = *value;
      escaped = false;
    } else if(*value == '\\') {
      escaped = true;
    } else if(*value == '"') {
      break;
    } else {
      out[length++] = *value;
    }
    ++value;
  }
  out[length] = '\0';
  return true;
}

int extract_int_value(const char* scope, const char* key, const int fallback) {
  const char* value = find_key(scope, key);
  if(value == nullptr) {
    return fallback;
  }
  return std::atoi(value);
}
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
int main() {
  stdio_init_all();
  flash_safe_execute_core_init();

  adc_init();
  adc_gpio_init(29);

  st7789.set_backlight(kBrightnessLevels[state.brightness_level]);

  if(cyw43_arch_init()) {
    while(true) {
      sleep_ms(250);
    }
  }

  graphics.set_font("bitmap6");
  state.passkey[0] = '\0';
  state.last_input = get_absolute_time();
  state.last_nap_end_ms = now_ms();

  buddyInit();
  load_persistent_state();
  update_battery_state();
  setup_ble();
  update_snapshot_banner();

#if BUDDY_UI_V2
  // Initialize V2 AFTER load_persistent_state — so the face engine,
  // seeded for blink randomness, gets a real boot-time value, and so
  // the first V2 frame reads the persisted motion/style settings. First
  // screen is Boot (~1.5 s), which hands off to Sync on first boot
  // (no bond) or Home on subsequent boots.
  ui_v2::core::init(&graphics, time_us_32(), now_ms());
#else
  render_screen();
#endif
  update_led();

  state.ui_timer.process = &ui_timer_handler;
  btstack_run_loop_set_timer(&state.ui_timer, kUiTickMs);
  btstack_run_loop_add_timer(&state.ui_timer);

  hci_power_control(HCI_POWER_ON);
  btstack_run_loop_execute();
  return 0;
}

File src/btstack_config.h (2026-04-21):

#ifndef _PICO_BTSTACK_BTSTACK_CONFIG_H
#define _PICO_BTSTACK_BTSTACK_CONFIG_H

#define ENABLE_LOG_INFO
#define ENABLE_LOG_ERROR
#define ENABLE_PRINTF_HEXDUMP
#define ENABLE_SCO_OVER_HCI

#ifdef ENABLE_BLE
#define ENABLE_GATT_CLIENT_PAIRING
#define ENABLE_L2CAP_LE_CREDIT_BASED_FLOW_CONTROL_MODE
#define ENABLE_LE_CENTRAL
#define ENABLE_LE_DATA_LENGTH_EXTENSION
#define ENABLE_LE_PERIPHERAL
#define ENABLE_LE_PRIVACY_ADDRESS_RESOLUTION
#define ENABLE_LE_SECURE_CONNECTIONS
#endif

#ifdef ENABLE_CLASSIC
#define ENABLE_L2CAP_ENHANCED_RETRANSMISSION_MODE
#define ENABLE_GOEP_L2CAP
#endif

#if defined(ENABLE_CLASSIC) && defined(ENABLE_BLE)
#define ENABLE_CROSS_TRANSPORT_KEY_DERIVATION
#endif

#define HCI_OUTGOING_PRE_BUFFER_SIZE 4
#define HCI_ACL_PAYLOAD_SIZE (1691 + 4)
#define HCI_ACL_CHUNK_SIZE_ALIGNMENT 4
#define MAX_NR_AVDTP_CONNECTIONS 1
#define MAX_NR_AVDTP_STREAM_ENDPOINTS 1
#define MAX_NR_AVRCP_CONNECTIONS 2
#define MAX_NR_BNEP_CHANNELS 1
#define MAX_NR_BNEP_SERVICES 1
#define MAX_NR_BTSTACK_LINK_KEY_DB_MEMORY_ENTRIES 2
#define MAX_NR_GATT_CLIENTS 1
#define MAX_NR_HCI_CONNECTIONS 2
#define MAX_NR_HID_HOST_CONNECTIONS 1
#define MAX_NR_HIDS_CLIENTS 1
#define MAX_NR_HFP_CONNECTIONS 1
#define MAX_NR_L2CAP_CHANNELS 4
#define MAX_NR_L2CAP_SERVICES 3
#define MAX_NR_RFCOMM_CHANNELS 1
#define MAX_NR_RFCOMM_MULTIPLEXERS 1
#define MAX_NR_RFCOMM_SERVICES 1
#define MAX_NR_SERVICE_RECORD_ITEMS 4
#define MAX_NR_SM_LOOKUP_ENTRIES 3
#define MAX_NR_WHITELIST_ENTRIES 16
#define MAX_NR_LE_DEVICE_DB_ENTRIES 16

#define MAX_NR_CONTROLLER_ACL_BUFFERS 3
#define MAX_NR_CONTROLLER_SCO_PACKETS 3

#define ENABLE_HCI_CONTROLLER_TO_HOST_FLOW_CONTROL
#define HCI_HOST_ACL_PACKET_LEN 1024
#define HCI_HOST_ACL_PACKET_NUM 3
#define HCI_HOST_SCO_PACKET_LEN 120
#define HCI_HOST_SCO_PACKET_NUM 3

#define NVM_NUM_DEVICE_DB_ENTRIES 16
#define NVM_NUM_LINK_KEYS 16

#define MAX_ATT_DB_SIZE 512

#define HAVE_EMBEDDED_TIME_MS
#define HAVE_ASSERT
#define HCI_RESET_RESEND_TIMEOUT_MS 1000

#define ENABLE_SOFTWARE_AES128
#define ENABLE_MICRO_ECC_FOR_LE_SECURE_CONNECTIONS

#define HAVE_BTSTACK_STDIN

#endif  // _PICO_BTSTACK_BTSTACK_CONFIG_H

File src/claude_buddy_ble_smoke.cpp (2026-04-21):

#include <cinttypes>
#include <cstdio>
#include <cstdlib>
#include <cstring>

#include "btstack.h"
#include "ble/gatt-service/nordic_spp_service_server.h"

#include "button.hpp"
#include "drivers/st7789/st7789.hpp"
#include "hardware/adc.h"
#include "libraries/pico_graphics/pico_graphics.hpp"
#include "pico/cyw43_arch.h"
#include "pico/stdlib.h"
#include "pico/time.h"
#include "pico_display_28.hpp"
#include "rgbled.hpp"

#include "claude_buddy_ble_smoke.h"

using namespace pimoroni;

namespace {

constexpr uint32_t kUiTickMs = 50;
constexpr float kAdcReferenceVolts = 3.3f;
constexpr float kVoltageDividerScale = 3.0f;
constexpr uint32_t kDefaultPasskey = 123456;

ST7789 st7789(PicoDisplay28::WIDTH, PicoDisplay28::HEIGHT, ROTATE_0, false, get_spi_pins(BG_SPI_FRONT));
PicoGraphics_PenRGB332 graphics(st7789.width, st7789.height, nullptr);
RGBLED led(PicoDisplay28::LED_R, PicoDisplay28::LED_G, PicoDisplay28::LED_B);

Button button_a(PicoDisplay28::A);
Button button_b(PicoDisplay28::B);
Button button_x(PicoDisplay28::X);
Button button_y(PicoDisplay28::Y);

// Keep the primary advertisement under the 31-byte BLE legacy limit so
// scanners reliably see the local name during discovery.
const uint8_t adv_data[] = {
    2, BLUETOOTH_DATA_TYPE_FLAGS, 0x06,
    12, BLUETOOTH_DATA_TYPE_COMPLETE_LOCAL_NAME, 'C', 'l', 'a', 'u', 'd', 'e', ' ', 'P', 'i', 'c', 'o',
};
const uint8_t adv_data_len = sizeof(adv_data);

const uint8_t scan_response_data[] = {
    17, BLUETOOTH_DATA_TYPE_COMPLETE_LIST_OF_128_BIT_SERVICE_CLASS_UUIDS,
    0x9e, 0xca, 0xdc, 0x24, 0x0e, 0xe5, 0xa9, 0xe0, 0x93, 0xf3, 0xa3, 0xb5, 0x01, 0x00, 0x40, 0x6e,
};
const uint8_t scan_response_data_len = sizeof(scan_response_data);

struct BuddyBleState {
  hci_con_handle_t connection_handle = HCI_CON_HANDLE_INVALID;
  bd_addr_t peer_addr{};
  bd_addr_type_t peer_addr_type = BD_ADDR_TYPE_LE_PUBLIC;
  bool advertising = true;
  bool connected = false;
  bool bonded = false;
  bool secure = false;
  bool prompt_active = false;
  bool last_a = false;
  bool last_b = false;
  uint16_t battery_mv = 0;
  bool usb_present = false;
  uint8_t battery_pct = 0;
  uint32_t approvals = 0;
  uint32_t denials = 0;
  int total = 0;
  int running = 0;
  int waiting = 0;
  int tokens_today = 0;
  char status_line[64] = "Advertising";
  char msg[64] = "Waiting for Claude";
  char last_rx[120] = "No RX yet";
  char owner[32] = "";
  char prompt_id[64] = "";
  char prompt_hint[80] = "";
  char passkey[16] = "123456";
  char tx_line[320] = "";
  bool tx_pending = false;
  btstack_context_callback_registration_t send_request{};
  btstack_timer_source ui_timer{};
} state;

btstack_packet_callback_registration_t hci_event_callback_registration;
btstack_packet_callback_registration_t sm_event_callback_registration;

uint16_t read_vsys_mv() {
  adc_select_input(3);
  sleep_us(10);
  const uint16_t raw = adc_read();
  const float volts = (static_cast<float>(raw) * kAdcReferenceVolts * kVoltageDividerScale) / 4095.0f;
  return static_cast<uint16_t>(volts * 1000.0f);
}

uint8_t estimate_percent(const uint16_t millivolts) {
  if(millivolts >= 4200) return 100;
  if(millivolts <= 3300) return 0;
  if(millivolts >= 4000) return static_cast<uint8_t>(80 + ((millivolts - 4000) * 20) / 200);
  if(millivolts >= 3700) return static_cast<uint8_t>(20 + ((millivolts - 3700) * 60) / 300);
  return static_cast<uint8_t>((millivolts - 3300) * 20 / 400);
}

bool contains_token(const char* haystack, const char* needle) {
  return std::strstr(haystack, needle) != nullptr;
}

int extract_int(const char* line, const char* key, const int fallback) {
  char needle[48];
  std::snprintf(needle, sizeof(needle), "\"%s\":", key);
  const char* start = std::strstr(line, needle);
  if(start == nullptr) {
    return fallback;
  }
  start += std::strlen(needle);
  return std::atoi(start);
}

void extract_string(const char* line, const char* key, char* out, const size_t out_size) {
  char needle[48];
  std::snprintf(needle, sizeof(needle), "\"%s\":", key);
  const char* start = std::strstr(line, needle);
  if(start == nullptr) {
    return;
  }
  start += std::strlen(needle);
  while(*start == ' ') {
    ++start;
  }
  if(*start != '"') {
    return;
  }
  ++start;
  const char* end = std::strchr(start, '"');
  if(end == nullptr) {
    return;
  }
  const size_t count = static_cast<size_t>(end - start);
  const size_t copy = count < (out_size - 1) ? count : (out_size - 1);
  std::memcpy(out, start, copy);
  out[copy] = '\0';
}

void request_can_send();

void queue_tx_line(const char* line_without_newline) {
  if(state.connection_handle == HCI_CON_HANDLE_INVALID) {
    return;
  }
  std::snprintf(state.tx_line, sizeof(state.tx_line), "%s\n", line_without_newline);
  state.tx_pending = true;
  request_can_send();
}

void send_status_reply() {
  char line[320];
  const char* owner_fragment = "";
  char owner_buf[64];
  if(state.owner[0] != '\0') {
    std::snprintf(owner_buf, sizeof(owner_buf), ",\"owner\":\"%s\"", state.owner);
    owner_fragment = owner_buf;
  }
  std::snprintf(
      line,
      sizeof(line),
      "{\"ack\":\"status\",\"ok\":true,\"data\":{\"name\":\"Claude Pico\"%s,\"sec\":%s,\"bat\":{\"pct\":%u,\"mV\":%u,\"mA\":0,\"usb\":%s},\"sys\":{\"up\":%llu,\"heap\":0},\"stats\":{\"appr\":%lu,\"deny\":%lu,\"vel\":0,\"nap\":0,\"lvl\":0}}}",
      owner_fragment,
      state.secure ? "true" : "false",
      static_cast<unsigned int>(state.battery_pct),
      static_cast<unsigned int>(state.battery_mv),
      state.usb_present ? "true" : "false",
      to_ms_since_boot(get_absolute_time()) / 1000,
      static_cast<unsigned long>(state.approvals),
      static_cast<unsigned long>(state.denials));
  queue_tx_line(line);
}

void ack_command(const char* command) {
  char line[96];
  std::snprintf(line, sizeof(line), "{\"ack\":\"%s\",\"ok\":true,\"n\":0}", command);
  queue_tx_line(line);
}

void request_can_send() {
  if(!state.tx_pending || state.connection_handle == HCI_CON_HANDLE_INVALID) {
    return;
  }
  state.send_request.callback = [](void* context) {
    UNUSED(context);
    if(!state.tx_pending || state.connection_handle == HCI_CON_HANDLE_INVALID) {
      return;
    }
    nordic_spp_service_server_send(
        state.connection_handle,
        reinterpret_cast<const uint8_t*>(state.tx_line),
        static_cast<uint16_t>(std::strlen(state.tx_line)));
    state.tx_pending = false;
  };
  nordic_spp_service_server_request_can_send_now(&state.send_request, state.connection_handle);
}
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

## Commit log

2026-04-21 Initial public snapshot
    [Claude_Pico_Battery_Clip.step, Claude_Pico_Battery_Clip.stl, Claude_Pico_Case_Main_Body.step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]
2026-04-21 Revise build guide story and assembly notes
2026-04-21 Refine V2 approval acting and demo flow
